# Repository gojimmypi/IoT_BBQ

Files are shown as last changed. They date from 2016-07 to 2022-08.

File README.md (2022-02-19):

# IoT BBQ

Project for [Making Embedded Systems](https://lms.classpert.com/classpertx/courses/making-embedded-systems/cohort) class.

See [Assignments](./Assignments/README.md)

The Imaginary Embedded System that does not exist for the _Making Embedded Systems_ class is the Barbeque Grill 
monitoring system project started (and abandoned) 5 years ago as noted below that was intially tinkered with using
an ESP8266 an the `LUA` language, but never completed. 

The `IoT_BBQ` system is a monitoring device to primarily measure the weight of the propane tank to ensure that
when it is time to cook, that the fuel supply is not nearly empty. Having an electronic scale monitoring the weight
is much more precise, accurate, and convenient as compared to the mechanical spring scales. A custom solution is also 
needed as the amount of available physical space is so limited, that even a bathroom scale is not practical for both 
size and viewing angle.

A premium version of this system will also include internal grill box temperature, as well as various atmospheric sensors, 
such as ambient temperature and pressure. 

Some sort of information display will be needed: either a local LCD panel and/or a web interface.

Components needed include:

- Controller board
- Power Supply
- Load cell (weight sensor) such as the [SparkFun HX711](https://www.sparkfun.com/products/13879) with this sample [Arduino Library](https://github.com/bogde/HX711). See also [non-arduino](https://github.com/nimaltd/HX711)
, and [ST forum](https://community.st.com/s/question/0D50X0000AusvItSQI/trying-to-interface-with-an-hx711-load-cell-amp)
- Temperature sensor
- Other atmospheric sensors
- Enclosure
- Mounting hardware

Yes, the [ST USB Driver](https://www.st.com/en/development-tools/stsw-link009.html) needs to be installed manually.

## Diagram:



## Weight Sensor

The HX711 weight sensor is powered with +3.3V and conencted to Arduino Header Pins `D8` (`ARD.D8` == `GPIO_PIN_8` == `PB2`) and `D9` (`GPIO_PIN_9`) located at `CN1` pins 1 and 2, 
as shown on page 50 of the [B-L475E-IOT01A (UM2153) User manual](https://www.st.com/resource/en/user_manual/um2153-discovery-kit-for-iot-node-multichannel-communication-with-stm32l4-stmicroelectronics.pdf)

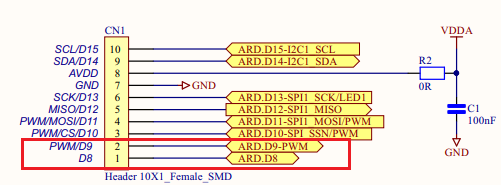
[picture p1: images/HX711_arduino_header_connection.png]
HX711_arduino_header_connection


## Display

The SSD1306 display is connected to I2C `SCL/D15` (`GPIO_PIN_15`) and `SDA/D14` (`GPIO_PIN_14`) located at `CN1` pins 9 and 10, 
as shown on page 50 of the [B-L475E-IOT01A (UM2153) User manual](https://www.st.com/resource/en/user_manual/um2153-discovery-kit-for-iot-node-multichannel-communication-with-stm32l4-stmicroelectronics.pdf)

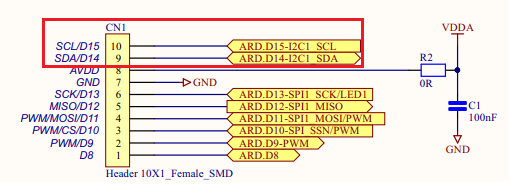
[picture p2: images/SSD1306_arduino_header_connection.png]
SSD1306_arduino_header_connection


## B-L475E-IOT01A Connections

HX711
- PD_SCK = GPIO_PIN_2; //  ARD.D8 = PB2  0x0004
- DOUT = GPIO_PIN_15;  //  ARD.D9 = PA15 0x8000

GPIO_init; old HX711
- GPIOB GPIO_PIN_8
- GPIOB GPIO_PIN_9

HAL_TIM_MspPostInit
- GPIOA / GPIO_PIN_0

LED
- GPIOA GPIO_PIN_5;
- GPIOB GPIO_PIN_14;

SSD1306
- DC GPIOB GPIO_PIN_14
- Reset GPIOA GPIO_PIN_8
- 

Button
- GPIOC, GPIO_PIN_13  (interrupt)

pwm_MX_GPIO_Init
- GPIOA GPIO_PIN_8

ConfigureI2CPins
- GPIOC GPIO_PIN_0 
- GPIOC GPIO_PIN_1

Pressure, Humidity, Temperature Sensors I2C. See [line 364 of stm32l475e_iot01.c](https://github.com/STMicroelectronics/STM32CubeL4/blob/5e1553e07706491bd11f4edd304e093b6e4b83a4/Drivers/BSP/B-L475E-IOT01/stm32l475e_iot01.c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):

- SCL = GPIOB GPIO_PIN_10
- SDA = GPIOB GPIO_PIN_11

### CN1

See Table 4 ARDUINO® connector pinout on page 31 of the [B-L475E-IOT01A (UM2153) User manual](https://www.st.com/resource/en/user_manual/um2153-discovery-kit-for-iot-node-multichannel-communication-with-stm32l4-stmicroelectronics.pdf):

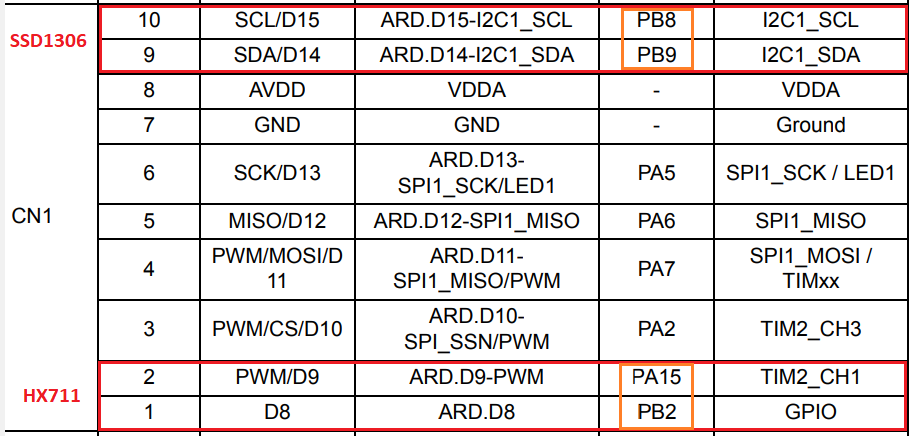
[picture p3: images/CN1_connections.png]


## Additional Resources

See also:

### Mechanical

- Statasys Grabcad Community [Propane Tank](https://grabcad.com/library/propane-tank)

## Electronics

- [STM32 Discovery Kits](https://www.st.com/en/evaluation-tools/stm32-discovery-kits.html#products)
- [ST-LINK, ST-LINK/V2, ST-LINK/V2-1, STLINK-V3 USB driver signed for Windows7, Windows8, Windows10](https://www.st.com/content/my_st_com/en/products/development-tools/software-development-tools/stm32-software-development-tools/stm32-utilities/stsw-link009.license=1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)
- [ARM MBED DISCO-L475VG-IOT01A (B-L475E-IOT01A](https://os.mbed.com/platforms/ST-Discovery-L475E-IOT01A/) (this is where the link on the OTG file points)
- [Mouser B-L475E-IOT01A Data Brief ](https://www.mouser.com/datasheet/2/389/b-l475e-iot01a-1848022.pdf)
- [Mouser Discovery Kit for IoT Node](https://www.mouser.com/pdfdocs/RS7706_IC_STM32L475E-IOT01A1_0517d.pdf) (this is the front and back of the insert card in for the shipped product)
- [Mouser STMicroelectronics B-L475E-IOT01A Discovery Kit for IoT Node](https://www.mouser.com/new/stmicroelectronics/stm-b-l475e-iot01a-kit/)

### Development

- [STM32Cube MCU Package for STM32L4 series and STM32L4 Plus series (HAL, Low-Layer APIs and CMSIS, USB, TouchSensing, File system, RTOS)](https://www.st.com/en/embedded-software/stm32cubel4.html#tools-software)
- [VisualGDB Developing STM32 projects with Visual Studio tutorial](https://visualgdb.com/tutorials/arm/stm32/)
- [STM32L4 Discovery kit IoT node software](https://www.st.com/en/evaluation-tools/b-l475e-iot01a.html#tools-software)
- [STM32L4 series of ultra-low-power MCUs](https://www.st.com/en/microcontrollers-microprocessors/stm32l4-series.html)
- [The FreeRTOS™ Reference Manual](https://www.freertos.org/fr-content-src/uploads/2018/07/FreeRTOS_Reference_Manual_V10.0.0.pdf)

### Example Code

- [bogde/HX711](https://github.com/bogde/HX711)
- [nimaltd/HX711](https://github.com/nimaltd/HX711/blob/master/hx711.c)
- [ODriveRobotics Samnple Code](https://github.com/odriverobotics/ODrive/blob/master/Firmware/Drivers/STM32/stm32_system.h)
- [RTOS Thread Management](https://www.keil.com/pack/doc/CMSIS/RTOS/html/group__CMSIS__RTOS__ThreadMgmt.html)

### Coding Reference

- Microchip [AVR035: Efficient C Coding for AVR](https://ww1.microchip.com/downloads/en/Appnotes/doc1497.pdf)
- [Idioms for using C++ in C programs (Part 1 of 2)](http://www.olivierlanglois.net/idioms_for_using_cpp_in_c_programs.html)

- [VS Code Extension: Markdown PDF](https://marketplace.visualstudio.com/items?itemName=yzane.markdown-pdf)

My original README follows:

# IoT_BBQ
ESP8266 Based Grill Temperature and Propane Tank Weight Project

First you need a NodeMCU ESP8266 like this one:

http://www.ebay.com/itm/400999083640

Note it has a CH340G USB chip, so works well with Windows 10

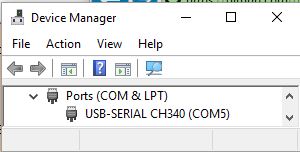
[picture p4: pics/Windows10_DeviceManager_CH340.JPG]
Windows Device Manager


Next, download flasher from https://github.com/nodemcu/nodemcu-flasher

In the \Resources\Binaries directory, there are Lua firmware images (one support floats, the other only ints)

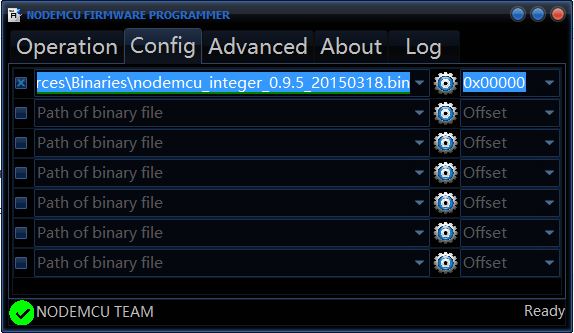
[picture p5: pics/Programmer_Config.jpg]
config setting


Once you've uploaded the image, this tool can be helpful for getting Lua code onto your device:

http://benlo.com/esp8266/ 

You can read more about NodeLUA here: https://nodelua.org/

Next, you will need a MAX6675 Module + K Type Thermocouple Temperature Sensor like this one: 

http://www.ebay.com/itm/400798924042

see this respository for spec sheet on MAX6675, or visit 

https://datasheets.maximintegrated.com/

Note that for connection to the ESP8266, you'll need to pull CS down to ground with a 10k resistor so the ESP8266 will boot.

I soldered a resistor on the board between those pins.

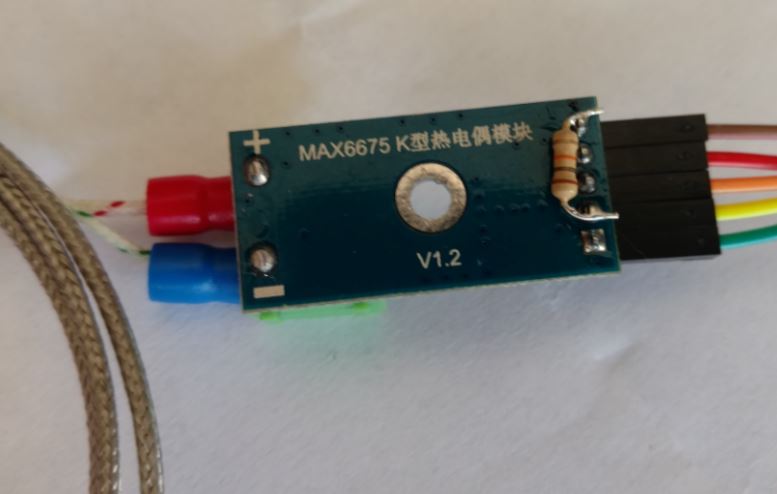
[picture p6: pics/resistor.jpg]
soldered resistor


Connect your thermocouple to the ESP8266 (see pics for pinout)

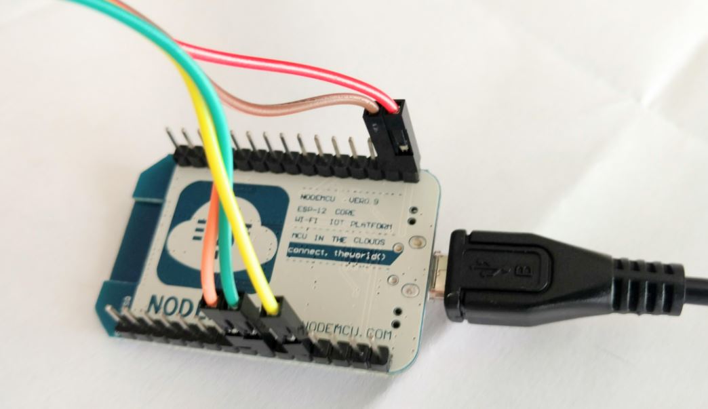
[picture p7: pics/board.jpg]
board wiring


Once everything is connected, setup ESP8266 to connect to WiFi. 

```Lua
wifi.setmode(wifi.STATION)
wifi.sta.config("yourWiFiName","yourWifFiPassword")
wifi.sta.connect()
```

Consider security issues of hard coding password. You can configure once & ESP8266 will remember after reboot.

Next, find your device on the local network segment. For this, I use fing:

https://play.google.com/store/apps/details?id=com.overlook.android.fing&hl=en

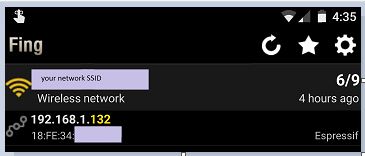
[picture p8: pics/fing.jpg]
fing


Once you find the device, click on it, and scan for open ports. You should have port 80 open:

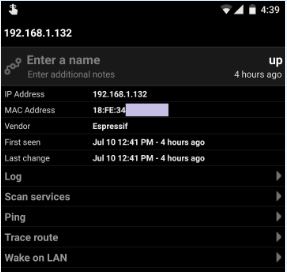
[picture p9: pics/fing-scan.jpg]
fing scan


If you found the ESP8266 on your network, upload the thermocouple.lua file:

thermocouple.lua upload

If everything is working, you'll see the temperature on your phone! (temperature shown in Celsius)

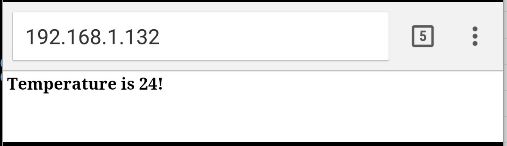
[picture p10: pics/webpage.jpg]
webpage sample


Load the file in init.lua to maintain web server operations after a reboot. I found that it is best to delete the init.lua file, reboot, then load a fresh init.lua when making changes. Again, fing is handy for detecting port 80 being open or not.

Next weekend, I will work on adding the weight sensor. I used one like this:

20KG Scale Load Cell Weight Weighing Sensor +HX711 Weighing Sensors AD Module 

http://www.ebay.com/itm/281916193412

feedback, comments, suggestions? contact me at gmail or twitter.

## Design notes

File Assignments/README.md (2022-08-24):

# Assignments for [Making Embedded Systems](https://lms.classpert.com/classpertx/courses/making-embedded-systems/cohort) class.

- [Exercise 1](./Exercise_1.md)
- [Exercise 2.1](./Exercise_2_1.md)
- [Exercise 2.2](./Exercise_2_2.md)
- [Exercise 3a](./Exercise_3a.md)
- [Exercise 3b](./Exercise_3b.md)  See also [Class Materials](https://drive.google.com/drive/folders/1xk9AmmLDqESqimDk_KvxHu6KfzpaYX9M), [spi_flash.h](https://drive.google.com/file/d/12dw-pZiKiK1vi4gv49W1x6np5uzCH_cV/view)
- [Exercise 4](./Exercise_4.md) 
- [Exercise 5](./Exercise_5.md) 
- [Exercise 6](./Exercise_6.md) 
- [Exercise 7](./Exercise_7.md) 
- [Exercise 8](./Exercise_8.md) 
- [Exercise 9](./Exercise_9.md)
- [Final Project](./Final_Project.md) and [Final Project Report](./Final_Project_Report.md)

[Final Project Video](https://youtu.be/YIoqKTbCUQQ)

# Final Project Submission

See [Final Project Submission](./Final_Project_Submission.md)

# Links

Hardware
- [STM32L4 Series](https://www.st.com/en/microcontrollers-microprocessors/stm32l4-series.html)
- [Mouser B-L475E-IOT01A1](https://www.mouser.com/ProductDetail/stmicroelectronics/b-l475e-iot01a1/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)
- [Mouser SPBTLE-RF](https://www.mouser.com/ProductDetail/STMicroelectronics/SPBTLE-RF?qs=k5OWtXsTJaq8f%252B3JiZyqyw%3D%3D), [Datasheet](https://www.mouser.com/datasheet/2/389/SGST_S_A0003533199_1-2576929.pdf)
- [ST B-L475E-IOT01A STM32L4 Discovery kit IoT node](https://www.st.com/en/evaluation-tools/b-l475e-iot01a.html#)
- [Migrating from STM32L4 and STM32L4+ to STM32L5 Series microcontrollers (AN5138)](https://www.st.com/resource/en/application_note/dm00476869-migrating-from-stm32l4-and-stm32l4-to-stm32l5-series-microcontrollers-stmicroelectronics.pdf)

Specifications

- [User Manual (57 pages) STM32L4 Discovery kit for the IoT node (B-L475E-IOT01A)](https://www.st.com/resource/en/user_manual/um2153-discovery-kit-for-iot-node-multichannel-communication-with-stm32l4-stmicroelectronics.pdf)
- [Data brief (4 pages) ST B-L475E-IOT01A](https://www.st.com/resource/en/data_brief/b-l475e-iot01a.pdf) Discovery kit for IoT node, multi-channel communication with STM32L4
- [STM32L475VG](https://www.st.com/en/microcontrollers-microprocessors/stm32l475vg.html#), [STM32L475xx datasheet (204 pages)](https://www.st.com/resource/en/datasheet/stm32l475vg.pdf)
- [STM32L475xx Datasheet AN4666](https://www.st.com/resource/en/datasheet/stm32l475vg.pdf)

Application Notes

- [Using the STM32F2, STM32F4 and STM32F7 Series DMA controller AN4031](https://www.st.com/content/ccc/resource/technical/document/application_note/27/46/7c/ea/2d/91/40/a9/DM00046011.pdf/files/DM00046011.pdf/jcr:content/translations/en.D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)
- [Using the STM32F0/F1/F3/Gx/Lx Series DMA controller AN2548](https://www.st.com/resource/en/application_note/an2548-using-the-stm32f0f1f3gxlx-series-dma-controller-stmicroelectronics.pdf)
- [Parallel synchronous transmission using GPIO and DMA](https://www.st.com/resource/en/application_note/an4666-parallel-synchronous-transmission-using-gpio-and-dma-stmicroelectronics.pdf)

Examples

- [B-L475E-IOT01A/Examples](https://github.com/STMicroelectronics/STM32CubeL4/tree/master/Projects/B-L475E-IOT01A/Examples) (not many examples)
- [STM32CubeL4/Projects/B-L475E-IOT01A/Examples/BSP/Src/](https://github.com/STMicroelectronics/STM32CubeL4/tree/master/Projects/B-L475E-IOT01A/Examples/BSP/Src)
- Digi-Key [Getting Started with STM32 - Timers and Timer Interrupts](https://www.digikey.com/en/maker/projects/getting-started-with-stm32-timers-and-timer-interrupts/d08e6493cefa486fb1e79c43c0b08cc6)

Peripherals

- [Inventek Systems ISM43362-M3G-L44-E/U Serial-to-WiFi Module](https://www.inventeksys.com/ism4336-m3g-l44-e-embedded-serial-to-wifi-module/), [ISM43362-M3G-L44 Datasheet](http://www.inventeksys.com/wp-content/uploads/ISM43362_M3G_L44_Functional_Spec.pdf)

GPIO
- [STM32 Understanding GPIO Settings](https://electronics.stackexchange.com/questions/156930/stm32-understanding-gpio-settings)

- [FreeRTOS: osDelay vs HAL_delay](https://stackoverflow.com/questions/42276313/freertos-osdelay-vs-hal-delay)

mbed

- [os.mbed.com DISCO-L475VG-IOT01A (B-L475E-IOT01A)](https://os.mbed.com/platforms/ST-Discovery-L475E-IOT01A/)
- [sensors](https://ide.mbed.com/compiler/#nav:/DISCO_L475VG_IOT01-Sensors-BSP/main.cpp;)

Visual GDB

- [Creating Advanced STM32CubeMX-based Projects with VisualGDB](https://visualgdb.com/tutorials/arm/stm32/cube/advanced/)
- [Controlling STM32 Hardware Timers using HAL](https://visualgdb.com/tutorials/arm/stm32/timers/hal/)
- [Using STM32 timers in PWM mode](https://visualgdb.com/tutorials/arm/stm32/pwm/)
- sysprogs github [visualgdb/ARM tutorials](https://github.com/sysprogs/tutorials/tree/master/visualgdb/ARM)
- [sysprogs/BSPTools](https://github.com/sysprogs/BSPTools)

RTOS

- [CMSIS-RTOS2 Documentation](https://arm-software.github.io/CMSIS_5/RTOS2/html/index.html)
- GitHub [CMSIS Version 5](https://github.com/ARM-software/CMSIS_5)
- [The FreeRTOS Reference Manual](https://www.freertos.org/fr-content-src/uploads/2018/07/FreeRTOS_Reference_Manual_V10.0.0.pdf)
- [stackoverflow: What are valid values of `HAL_NVIC_SetPriority()` when using STM32 and FreeRTOS?](https://stackoverflow.com/questions/50243996/what-are-valid-values-of-hal-nvic-setpriority-when-using-stm32-and-freertos)
- FreeRTOS [Memory Management](https://www.freertos.org/a00111.html)
- STM32CubeL4 FreeRTOS [xPortGetFreeHeapSize](https://github.com/STMicroelectronics/STM32CubeL4/blob/master/Middlewares/Third_Party/FreeRTOS/Source/portable/MemMang/heap_4.c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)

Debuggers

- [ST-LINK/V2 in-circuit debugger/programmer for STM8 and STM32](https://www.st.com/en/development-tools/st-link-v2.html)
- [Segger J-Link / J-Trace User Guide](https://www.segger.com/downloads/jlink/UM08001)
- [Converting ST-LINK On-Board Into a J-Link](https://www.segger.com/products/debug-probes/j-link/models/other-j-links/st-link-on-board/)

Sample Code

- [ST community: delay in a microsecond(us)](https://community.st.com/s/question/0D50X0000BGkxmCSQR/stm32l462-delay-in-a-microsecondus)
- [a-podshivalov/RIOT](https://github.com/a-podshivalov/RIOT) sample code
- [bogde/HX711](https://github.com/bogde/HX711/blob/master/src/HX711.cpp)
- [ArduinoCore-samd/cores/arduino/wiring_private.h](https://github.com/arduino/ArduinoCore-samd/blob/master/cores/arduino/wiring_private.h)
- [ArduinoCore-avr/cores/arduino/wiring_shift.c](https://github.com/arduino/ArduinoCore-avr/blob/9f8d27f09f3bbd1da1374b5549a82bda55d45d44/cores/arduino/wiring_shift.c) - original code for [shiftIn()](https://www.arduino.cc/reference/en/language/functions/advanced-io/shiftin/)
- [logicalelegance/midifun/Core/Console/console.c](https://github.com/logicalelegance/midifun/blob/master/Core/Console/console.c)
- [stackoverflow: STM32 HAL timer interrupt isn't triggered](https://stackoverflow.com/questions/40323461/stm32-hal-timer-interrupt-isnt-triggered)
- [stackoverflow: STM32F3 Discovery - Implement GPIO-Interrupt](https://stackoverflow.com/questions/40057581/stm32f3-discovery-implement-gpio-interrupt)
- [STM32-libraries/Drivers/LCD/Adafruit_GFX.h](https://github.com/mindThomas/STM32-libraries/blob/master/Drivers/LCD/Adafruit_GFX.h)

IoT Management Tools

- [What Is IoT Device Management and Why Do You Need It?](https://www.digi.com/blog/post/what-is-iot-device-management)
- [Memfault - Cloud Debugging and Observability for Your IoT Devices](https://memfault.com/); [Monitoring Fleet Health with Heartbeat Metrics](https://interrupt.memfault.com/blog/device-heartbeat-metrics); [Defensive Programming](https://interrupt.memfault.com/blog/defensive-and-offensive-programming)
- [Tyler Hoffman on embedded.fm to discuss the issues associated with embedded devices at consumer scale](https://embedded.fm/episodes/390).
- [Monitor your entire Azure IoT environment with Datadog](https://www.datadoghq.com/dg/monitor/azure-iot/)
- [ThingsBoard Open-source IoT Platform](https://thingsboard.io/)
- [Azure IoT](https://azure.microsoft.com/en-us/overview/iot/#overview)
- [AWS IoT Device Management](https://aws.amazon.com/iot-device-management/)

Hard Faulkts

- [How to debug a HardFault on an ARM Cortex-M MCU](https://interrupt.memfault.com/blog/cortex-m-fault-debug#fn:8)
- [Slides from live class](https://drive.google.com/file/d/11M6Tn6bw0GAD549te2_HMGIEa5ajErI1/view?usp=sharing)

Other Stuff

- wikipedia [.bss block starting symbol](https://en.wikipedia.org/wiki/.bss)
- [pinout](https://pinout.readthedocs.io/en/latest/)
- [cmocka unit testing framework for C with support for mock objects](https://cmocka.org/)
- [asciiflow.com](https://asciiflow.com/#/)
- [app.diagrams.net](https://app.diagrams.net/)
- [lucidChart Block diagram maker](https://www.lucidchart.com/pages/examples/block-diagram-maker)
- [drawio-desktop](https://github.com/jgraph/drawio-desktop/releases/tag/v15.8.7)
- [Everything You Never Wanted To Know About Linker Script](https://mcyoung.xyz/2021/06/01/linker-script/)
- [Basic Concepts in Interrupts](https://web.sonoma.edu/users/f/farahman/sonoma/courses/es310/310_arm/lectures/Chapter_11_Interrupts_ARM.pdf) from [EE 310/310L: Microprocessors and System Design - Introducing ARM](https://web.sonoma.edu/users/f/farahman/sonoma/courses/es310/310_arm/)
- [STM32Cube initialization code generator](https://www.st.com/en/development-tools/stm32cubemx.html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),  specifically [STM32 configuration and initialization C code generation](https://www.st.com/resource/en/data_brief/stm32cubemx.pdf)
- [hackaday stm32cubemx makes makefiles](https://hackaday.com/2017/07/15/stm32cubemx-makes-makefiles/)
- [godbolt.org](https://godbolt.org/)

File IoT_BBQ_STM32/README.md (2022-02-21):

# IoT BBQ STM32

## Build from Visual Studio

The [IoT_BBQ_STM32](https://github.com/gojimmypi/IoT_BBQ/blob/main/IoT_BBQ_STM32/IoT_BBQ_STM32.sln) is a Visual Studio 2019 solution file with a SysProgs VisualGDB extension project.

Build simply by right-click and build...

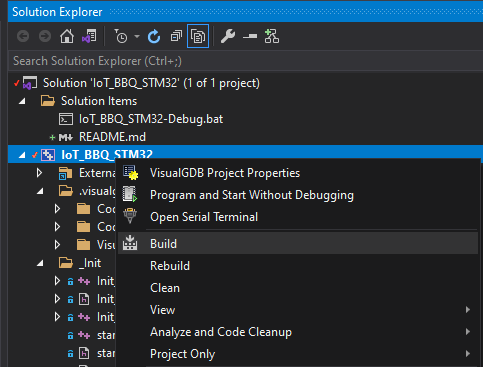
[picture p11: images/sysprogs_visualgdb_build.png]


## Build from a batch file:

Assumes toolchain is installed in: `c:\SysGCC\arm-eabi\bin\arm-none-eabi-gcc.exe`

```
SET WORKSPACE=C:\workspace\
c:
if not exist "%WORKSPACE%" mkdir "%WORKSPACE%"

cd "%WORKSPACE%"
if exist "%WORKSPACE%" goto error

git clone https://github.com/gojimmypi/IoT_BBQ.git
cd "%WORKSPACE%"
cd IoT_BBQ\IoT_BBQ_STM32

goto done
:error
echo Error 

:done
echo done!

```

For more information, see [Final Project](../Assignments/Final_Project.md).

Testing the new [Include diagrams in your Markdown files with Mermaid](https://github.blog/2022-02-14-include-diagrams-markdown-files-mermaid/) feature:

# Main

```mermaid
graph TD
    A[Startup] -->|Init| B(Start Threads)
    B --> LED1[LED1 Blinky]
    B --> LED2[LED2 Blinky]
    B --> UART
    B --> DISPLAY
    B --> PWM[PWM]
    LED1 --> ShowWeight[Display Weight]
    ShowWeight --> ShowPressure[Display Pressure]
    ShowPressure --> Blinky1State{LED_GetMode}
    Blinky1State --> |IsBlinking| LED1_blink[LED1 Blink]
    Blinky1State --> |AlwaysOn| LED1_On[LED1 On]
    Blinky1State --> |AlwaysOff| LED1_Off[LED1 Off]
    Blinky1State --> |default| LED1_default[Set Mode IsBlinking]
    LED1_blink --> ShowWeight
    LED1_On --> ShowWeight
    LED1_Off --> ShowWeight
    LED1_default --> ShowWeight
    PWM -->|One| D[experiments]
```

# Overall System

```mermaid
graph TD
    A[Startup] -->|Init| B(Start Threads)
    B --> LED1[LED1 Blinky]
    B --> LED2[LED2 Blinky]
    B --> UART
    B --> DISPLAY_Thread1[Display]
    B --> PWM[PWM]

    LED1 --> ShowWeight[Display Weight]
    ShowWeight --> ShowPressure[Display Pressure]
    ShowPressure --> Blinky1State{LED_GetMode}
    Blinky1State --> |IsBlinking| LED1_blink[LED1 Blink]
    Blinky1State --> |AlwaysOn| LED1_On[LED1 On]
    Blinky1State --> |AlwaysOff| LED1_Off[LED1 Off]
    Blinky1State --> |default| LED1_default[Set Mode IsBlinking]
    LED1_blink --> ShowWeight
    LED1_On --> ShowWeight
    LED1_Off --> ShowWeight
    LED1_default --> ShowWeight

    LED2 --> Blinky2State{LED_GetMode}
    Blinky2State --> |IsBlinking| LED2_blink[blink_Count = 1]
    Blinky2State --> |AlwaysOn| LED2_On[blink_Count = 2]
    Blinky2State --> |AlwaysOff| LED2_Off[blink_Count = 3]
    Blinky2State --> |default| LED2_default[blink_Count = 4]
    LED2_blink --> LED2
    LED2_On --> LED2
    LED2_Off --> LED2
    LED2_default --> LED2

    DISPLAY_Thread1 --> InitDisplay
    InitDisplay --> CheckForLongPress{Long Press?}
    CheckForLongPress --> |yes|Tare
    CheckForLongPress --> |no|ShowWeightDisplay
    Tare --> ShowWeightDisplay
    ShowWeightDisplay --> CheckForLongPress

    PWM -->|One| D[experiments]

```  

# Threads

```mermaid
graph TD
    A[Startup] -->|Init| B(Start Threads)
    B --> LED1[LED1 Blinky]
    B --> LED2[LED2 Blinky]
    B --> UART
    B --> DISPLAY_Thread1[Display]
    B --> PWM[PWM]
```

# LED1

```mermaid
graph TD
    LED1 --> ShowWeight[Display Weight]
    ShowWeight --> ShowPressure[Display Pressure]
    ShowPressure --> Blinky1State{LED_GetMode}
    Blinky1State --> |IsBlinking| LED1_blink[LED1 Blink]
    Blinky1State --> |AlwaysOn| LED1_On[LED1 On]
    Blinky1State --> |AlwaysOff| LED1_Off[LED1 Off]
    Blinky1State --> |default| LED1_default[Set Mode IsBlinking]
    LED1_blink --> ShowWeight
    LED1_On --> ShowWeight
    LED1_Off --> ShowWeight
    LED1_default --> ShowWeight
```

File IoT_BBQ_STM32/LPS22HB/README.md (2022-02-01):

LPS22HB MEMS nano pressure sensor: 260-1260 hPa absolute digital output barometer

See https://www.st.com/resource/en/datasheet/lps22hb.pdf

Sample code: https://github.com/STMicroelectronics/STM32CubeL4/tree/master/Drivers/BSP/B-L475E-IOT01

See also:    https://github.com/STMicroelectronics/STM32CubeL4/blob/master/Drivers/BSP/B-L475E-IOT01/stm32l475e_iot01.c

Uumidity:    https://github.com/STMicroelectronics/STM32CubeL4/blob/master/Drivers/BSP/B-L475E-IOT01/stm32l475e_iot01_hsensor.h

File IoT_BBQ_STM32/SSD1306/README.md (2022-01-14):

# stm32-ssd1306

STM32 library for working with OLEDs based on SSD1306, supports I2C and 4-wire SPI.
It also works with SH1106, SH1107 and SSD1309 which are compatible with SSD1306.

Please see `ssd1306/ssd1306_conf_template.h` and `examples` directory for more details.

See also:

* https://github.com/afiskon/stm32-i2c-lcd-1602
* https://github.com/afiskon/stm32-ssd1351
* https://github.com/afiskon/stm32-st7735
* https://github.com/afiskon/stm32-ili9341

The code is based on
[4ilo/ssd1306-stm32HAL](https://github.com/4ilo/ssd1306-stm32HAL) library
developed by Olivier Van den Eede ( [@4ilo](https://github.com/4ilo) ) in 2016.

There is a [DuyTrandeLion/nrf52-ssd1309](https://github.com/DuyTrandeLion/nrf52-ssd1309) port to nRF52 of this library made by [@DuyTrandeLion](https://github.com/DuyTrandeLion) in 2020.

See also: [Sysprogs VisualGDB Using the I2C Interface on the STM32 Devices](https://visualgdb.com/tutorials/arm/stm32/i2c/)

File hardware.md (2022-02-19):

Hardware used for [Making Embedded Systems](https://lms.classpert.com/classpertx/courses/making-embedded-systems/cohort) class.

Dev Board: [B-L475E-IOT01A1](https://www.st.com/en/evaluation-tools/b-l475e-iot01a.html)

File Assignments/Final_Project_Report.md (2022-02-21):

# Final Project Report

This Final Project Report is a supplement to the [Final Project Minimum Project Requirement Detail](./Final_Project.md).
An embedded microscontroller was used to create a propane tank weight measurement system. 
[Source code](https://github.com/gojimmypi/IoT_BBQ/tree/main/IoT_BBQ_STM32) is available on GitHub.

See also the [YouTube Video](https://youtu.be/YIoqKTbCUQQ):

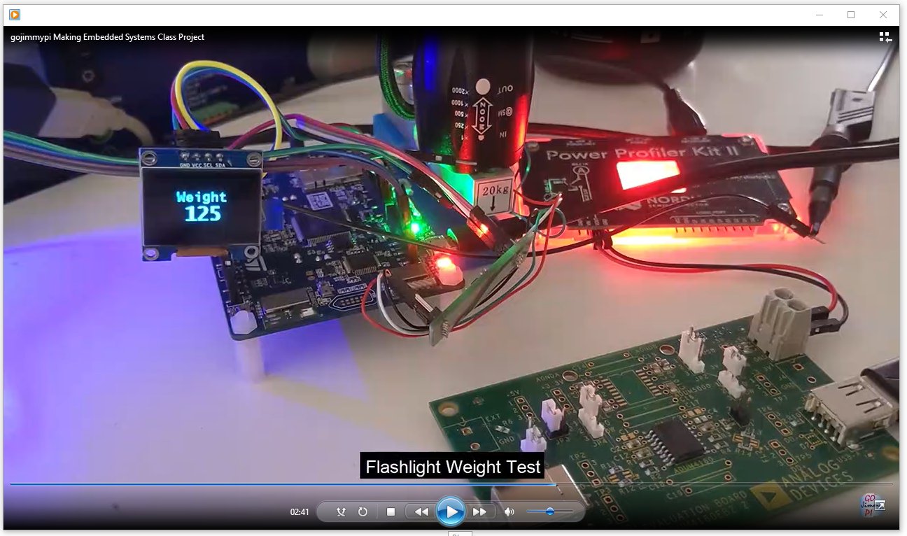
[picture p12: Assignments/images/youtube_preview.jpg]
(https://youtu.be/YIoqKTbCUQQ)

<br/><br/>

## Application Description

This application is an embedded controller to monitor grill propane tank weight to replace the existing mechanical spring scale:

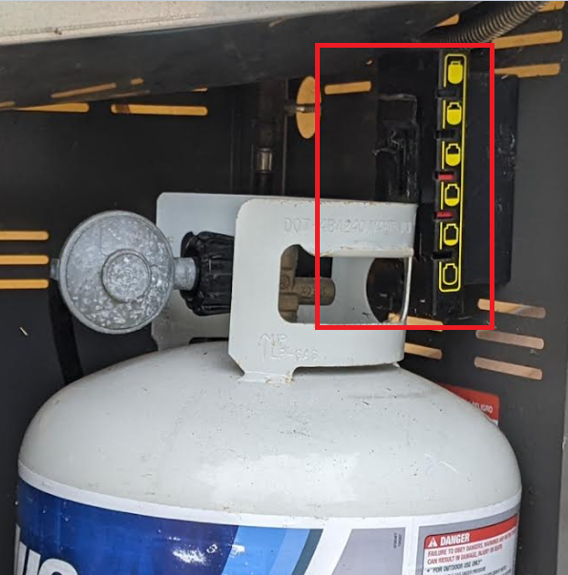
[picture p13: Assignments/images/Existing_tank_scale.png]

<br/><br/>

## Hardware Description

This project uses the [STM32L475VG](https://www.st.com/resource/en/datasheet/stm32l475vg.pdf), 
part of the [STM32 Ultra Low Power](https://www.st.com/en/microcontrollers-microprocessors/stm32-ultra-low-power-mcus.html) Arm Cortex-M4 32-bit MCU+FPU series
found on the  [B-L475E-IOT01A Discovery Board](https://www.st.com/resource/en/user_manual/um2153-discovery-kit-for-iot-node-multichannel-communication-with-stm32l4-stmicroelectronics.pdf).
<br/><br/>

## Software description

The application is written in C/C++ and targets the STM32 ARM Platform. 
<br/><br/>

### Describe the code in general

The code is a multi-threaded FreeRTOS embedded application. There are 5 threads named LED1, LED2, UART1, DISPLAY, and PWM.

#### LED1 Thread

The [LED1 Thread](https://github.com/gojimmypi/IoT_BBQ/blob/main/IoT_BBQ_STM32/_main_LED_Thread1.c) is a simple state machine and controls LED1 (blinky, on, or off).
This thread also sends pressure reading and scale weight text to the UART.
<br/><br/>

#### LED2 Thread

The [LED1 Thread](https://github.com/gojimmypi/IoT_BBQ/blob/main/IoT_BBQ_STM32/_main_LED_Thread2.c) monitors the state machine and blinks LED2 depending on the current state:

* `IsBlinking` - one blink
* `AlwaysOn` - two blinks
* `AlwaysOff` - three blinks
<br/><br/>

#### UART1 Thread

Just to test RTOS concurrency (and hard fault avoidance!) the [UART1 Thread]() sends a "Hello UART1" message
to the UART about every 1.35 seconds. An odd number was chosen to ensure pseudo-random conflicts in timing
with other messages.

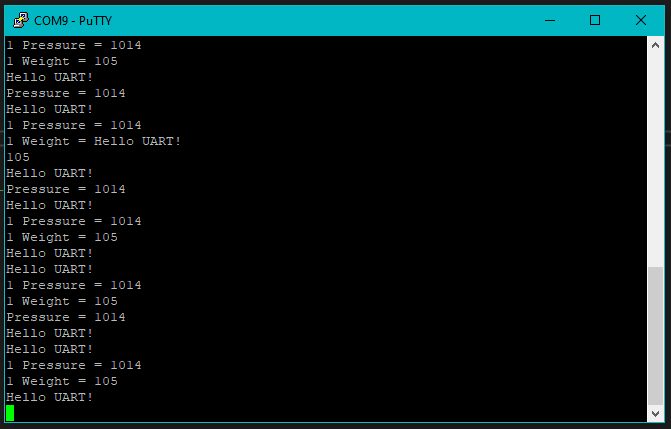
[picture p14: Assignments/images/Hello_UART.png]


This particular screen snip (above) is interesting. Note the seemingly stray "105" value. Apparently this is where the thread tried to grab a mutex to use the UART, but one was not available
on a timely basis, so it skipped the entire "1 weight" part of the message. Recall this occurs in [two steps](https://github.com/gojimmypi/IoT_BBQ/blob/29255d7aa78ec70aa6fd3b76e06db336202eda09/IoT_BBQ_STM32/_main_LED_Thread1.c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):

```
        UART_TxMessageIntValue(WeightMessage, sizeof(WeightMessage), CurrentTankWeight);
        // (RTOS Thread swtich occured around here)
        UART_TxMessage(CrLf, sizeof(CrLf));
```
<br/><br/>

#### DISPLAY Thread

The [Display Thread](https://github.com/gojimmypi/IoT_BBQ/blob/main/IoT_BBQ_STM32/DISPLAY/DISPLAY.cpp) is where the scale is monitored and the value displayed on the screen.
There's also a small state machine monitoring for a button long press to then tare the scale and save the offset value to flash.
<br/><br/>

#### PWM Thread

The [PWM thread](https://github.com/gojimmypi/IoT_BBQ/blob/main/IoT_BBQ_STM32/_main_pwm_thread.c) is included only for "interesting" experiements and is not required for basic functionality.

After some initial code experiments, the thread runs in a loop sending barometric pressure reading to the UART every 2 seconds.

Code Explorer View of [main()](https://github.com/gojimmypi/IoT_BBQ/blob/main/IoT_BBQ_STM32/_main.c)

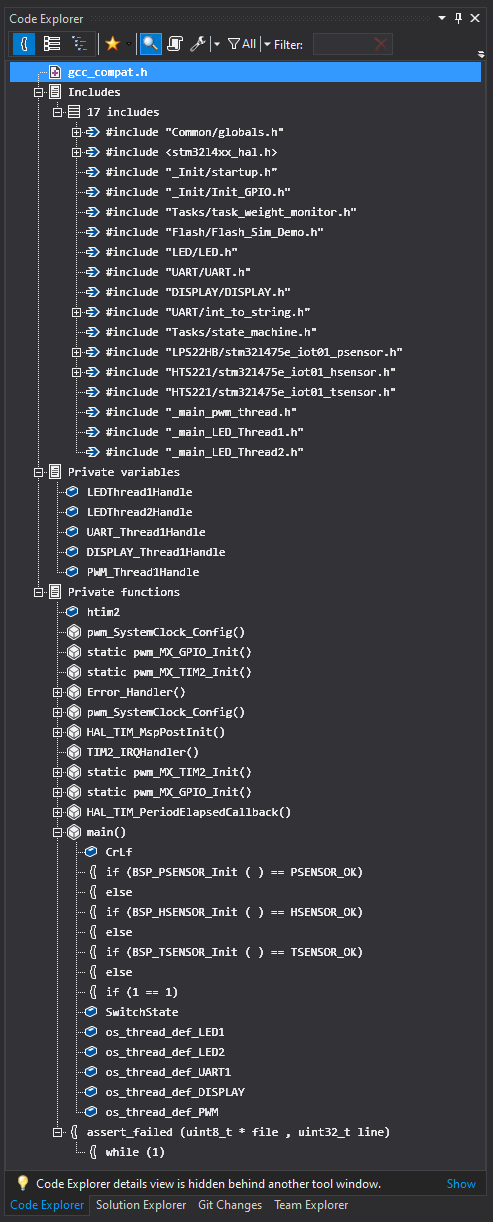
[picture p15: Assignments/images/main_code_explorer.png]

<br/><br/>

### Describe the parts you wrote in some detail (maybe 3-5 sentences per module)

The main code repository can be found at [github.com/gojimmypi/IoT_BBQ/tree/main/IoT_BBQ_STM32](https://github.com/gojimmypi/IoT_BBQ/tree/main/IoT_BBQ_STM32). MIT License.

* [Display Code](https://github.com/gojimmypi/IoT_BBQ/tree/main/IoT_BBQ_STM32/DISPLAY) was written specifically for this project. MIT License.

* [Flash Config](https://github.com/gojimmypi/IoT_BBQ/blob/main/IoT_BBQ_STM32/Flash/flash_config.h) was created from scratch for this project. MIT license.

* [LED Blinky and State Machine](https://github.com/gojimmypi/IoT_BBQ/tree/main/IoT_BBQ_STM32/LED) created by gojimmypi for this project. MIT license.

* [UART](https://github.com/gojimmypi/IoT_BBQ/tree/main/IoT_BBQ_STM32/UART) created for this project, MIT license. Uses [stm32l4xx_hal.h](https://github.com/STMicroelectronics/STM32CubeL4/blob/master/Drivers/STM32L4xx_HAL_Driver/Inc/stm32l4xx_hal.h) 
assumed to still be [BSD 3-Clause license](https://github.com/STMicroelectronics/STM32CubeL4/blob/d023c0d560ace11509f9b761c8913a9e48fcf194/Drivers/STM32L4xx_HAL_Driver/Src/stm32l4xx_hal.c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)
<br/><br/>

### Describe code you re-used from other sources, including the licenses for those

This project was created using the [Sysprogs VisualGDB Extension](https://visualgdb.com/?features=embedded) for [Visual Studio 2019](https://docs.microsoft.com/en-us/visualstudio/releases/2019/release-notes).
A tiny amount of initialization code was generated using the [STM32CubeIDE](https://www.st.com/en/development-tools/stm32cubeide.html). 

* [HX711 Arduino Library](https://github.com/bogde/HX711) was ported to this STM32 HAL environment with FreeRTOS support. MIT License.

* [STM hsensor HAL](https://github.com/STMicroelectronics/STM32CubeL4/blob/master/Drivers/BSP/B-L475E-IOT01/stm32l475e_iot01_hsensor.c) BSD 3-Clause license. 

* [STM Pressure Sensor HAL](https://github.com/STMicroelectronics/STM32CubeL4/blob/master/Drivers/BSP/B-L475E-IOT01/stm32l475e_iot01_psensor.h) BSD 3-Clause license

* [ssd1306 display driver](https://github.com/afiskon/stm32-ssd1306) was created by Aleksander Alekseev and [modified](https://github.com/gojimmypi/IoT_BBQ/commits/main/IoT_BBQ_STM32/SSD1306) for this project.  MIT License

* [Flash HAL](https://github.com/STMicroelectronics/STM32CubeL4/blob/master/Drivers/STM32L4xx_HAL_Driver/Src/stm32l4xx_hal_flash.c). Assumed to still be Licensed by ST under BSD 3-Clause license, 
but the [license File is now blank](https://github.com/STMicroelectronics/STM32CubeL4/issues/63).  

Additional thanks to Elecia White (the Making Embedded Systems Instructor) for the code review, in particular to help find the cause of those nasty Hard Faults.
Also thanks to the class mentors Erin, Daniel, Thomas, and Jeff... as well as all my classmates on the discord channel. A lot of smart and creative people 
with all sorts of interesting ideas!
<br/><br/>

## Diagram(s) of the architecture

Show below is the basic diagram of the architecture. The network feature has not yet been implemented:

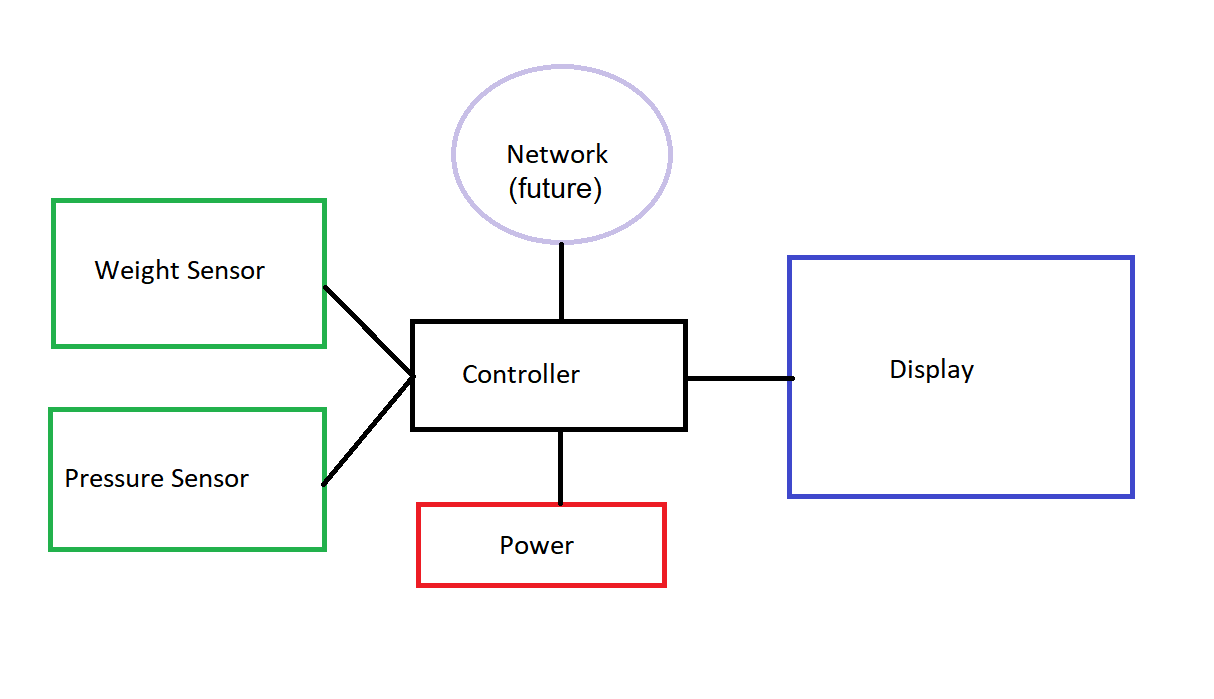
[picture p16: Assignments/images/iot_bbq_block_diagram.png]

<br/><br/>

## Build Instructions

There are two options for building: the GUI from Visual Studio and a command-line batch file, both on Windows.
<br/><br/>

#### Build in Visual Studio

Open the Visual Studio Solution File called [IoT_BBQ_STM32.sln](https://github.com/gojimmypi/IoT_BBQ/blob/main/IoT_BBQ_STM32/IoT_BBQ_STM32.sln). 
Find the `IoT_BBQ_STM32` Project. Right-click and select "Build...":

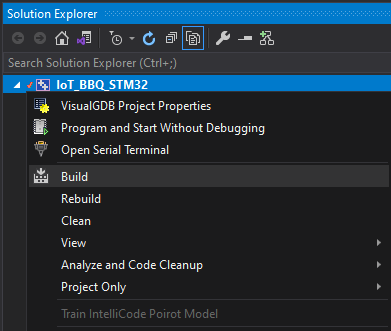
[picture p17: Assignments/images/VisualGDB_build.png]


To build and upload code, simply click the green `VisualGDB Debugger` button:



If the build was successful, the code will be sent to the board:

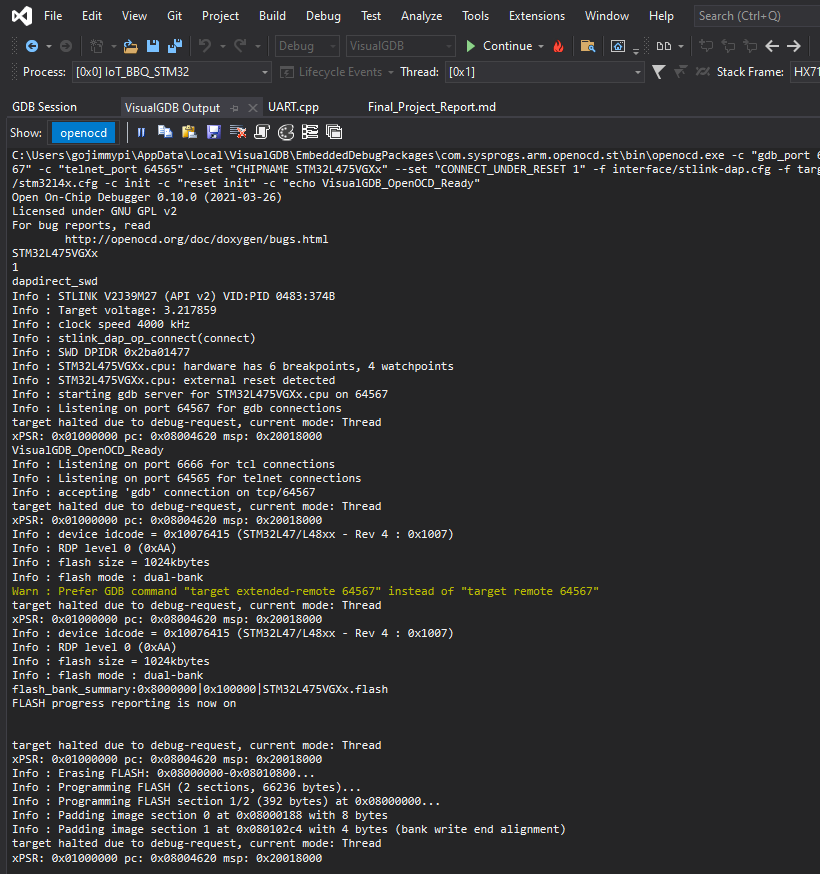
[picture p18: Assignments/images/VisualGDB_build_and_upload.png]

<br/><br/>

#### Build from Command-Line

If the STM32 toolchain is installed (for Windows) there's also an auto-generated [batch file](https://github.com/gojimmypi/IoT_BBQ/blob/main/IoT_BBQ_STM32/IoT_BBQ_STM32-Debug.bat) to build from command-line.

```

```

See also [Project Readme Build Instructions](https://github.com/gojimmypi/IoT_BBQ/tree/main/IoT_BBQ_STM32#build-from-a-batch-file)
<br/><br/>

### How to build the system (including the toolchain(s))

The only toolchain required for this project is the [VisualGDB Extension](https://visualgdb.com/). 
See the [Developing STM32 projects with Visual Studio](https://visualgdb.com/tutorials/arm/stm32/) walk-through.

These settings are included the project solution file but included here for reference:

Project Config Step 1:

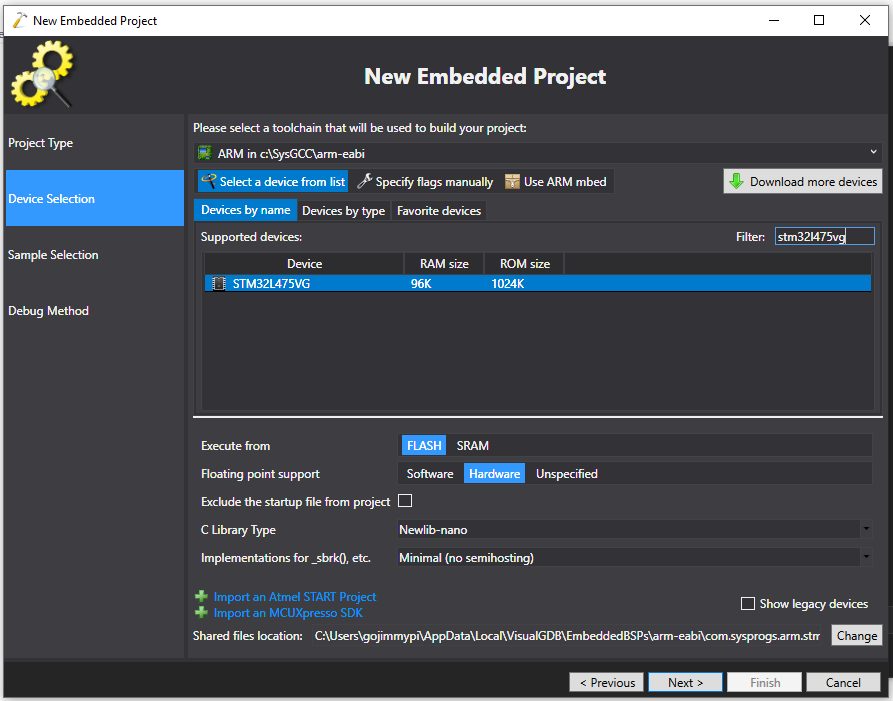
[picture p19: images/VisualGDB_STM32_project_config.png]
VisualGDB_STM32_project_config


Project Config Step 2:

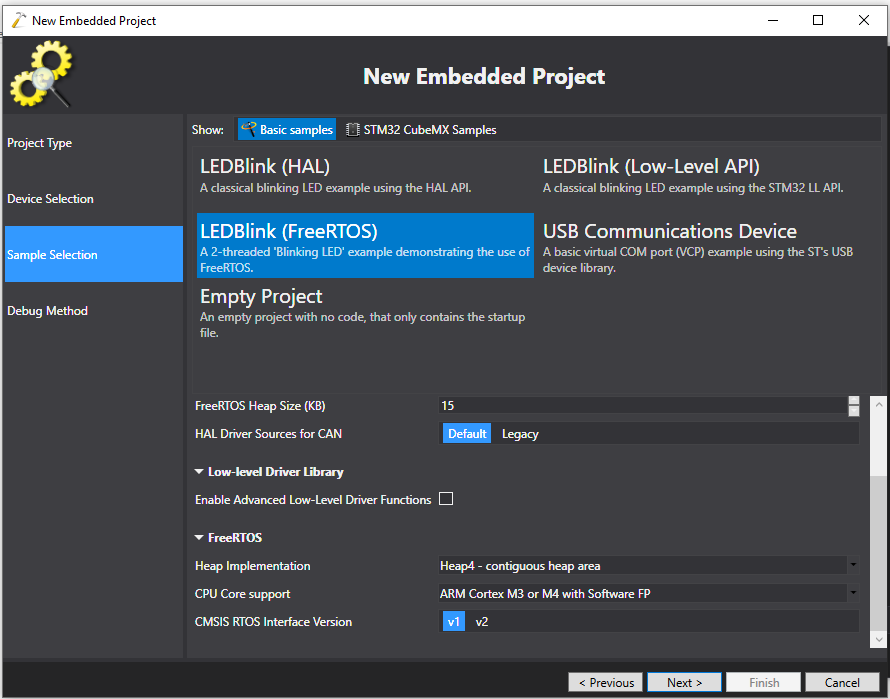
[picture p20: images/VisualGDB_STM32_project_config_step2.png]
VisualGDB_STM32_project_config_step2


Project Config Step 3:

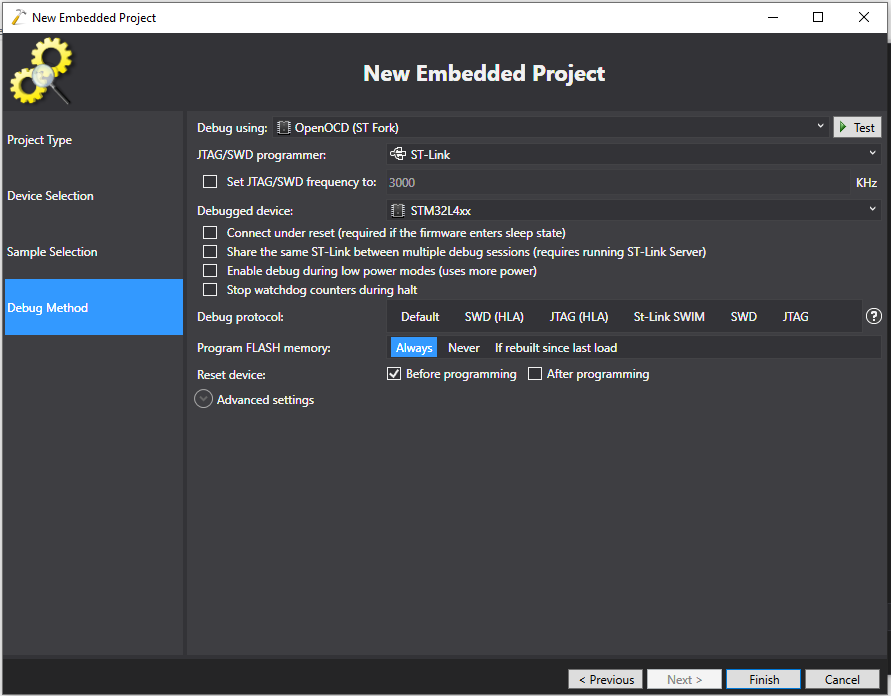
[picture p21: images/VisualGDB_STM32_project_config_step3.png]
VisualGDB_STM32_project_config_step3


See above for the [build instructions](https://github.com/gojimmypi/IoT_BBQ/blob/main/Assignments/Final_Project_Report.md#build-instructions).

<br/><br/>

### Hardware

- Mouser [ST B-L475E-IOT01A1](https://www.mouser.com/ProductDetail/stmicroelectronics/b-l475e-iot01a1/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)
- Amazon [SSD1306 I2C Serial](https://www.amazon.com/dp/B08KY21SR2/)
- Sparkfun [Load Cell Amplifier HX711](https://www.sparkfun.com/products/13879?_ga=2.84341273.1032917369.1645317851-1685161029.1637878826)
- Adafruit [Strain Gauge Load Cell - 4 Wires - 20Kg](https://www.adafruit.com/product/4543)

Hardware wiring diagram:

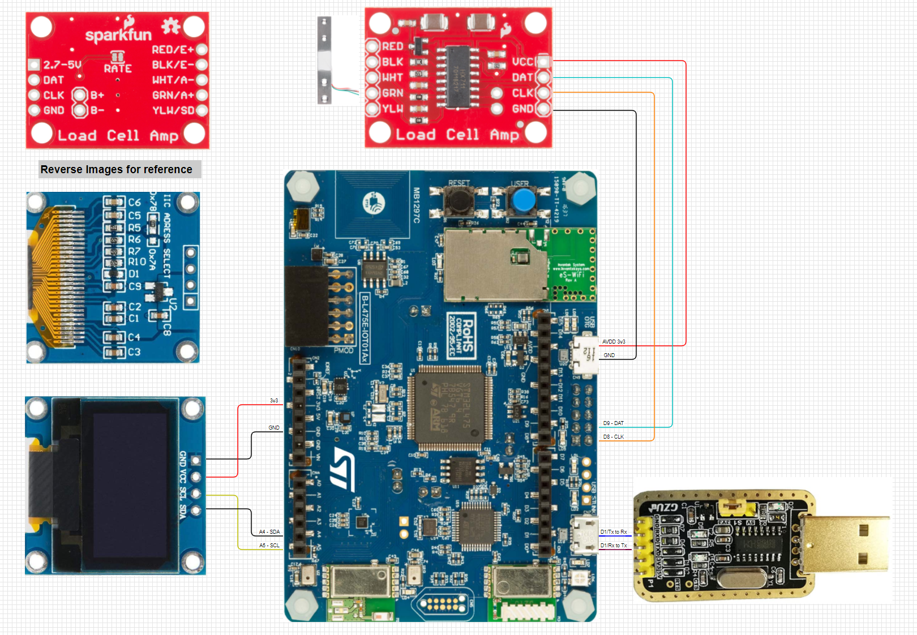
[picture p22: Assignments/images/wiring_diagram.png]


<br/><br/>

### Software

The source code can be downloaded from [GitHub gojimmypi/IoT_BBQ](https://github.com/gojimmypi/IoT_BBQ). The only other software needed is Visual Studio and
VisualGDB (and an internet connection, as VissualGDB will download and install toolchains and libraries as needed.) 

<br/><br/>

### How you debugged and tested the system

All of the development and debugging was completed in Visual Studio using breakpoints and the single-step-debugging features available from the VisualGDB extension.

Single-step inspection:

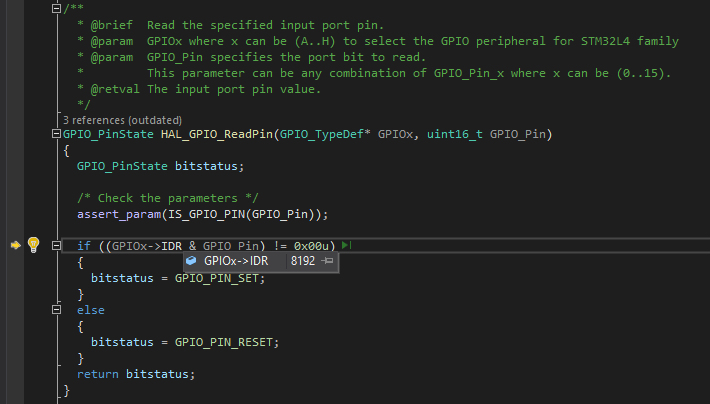
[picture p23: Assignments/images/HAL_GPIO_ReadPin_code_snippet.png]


Heap pointer check:

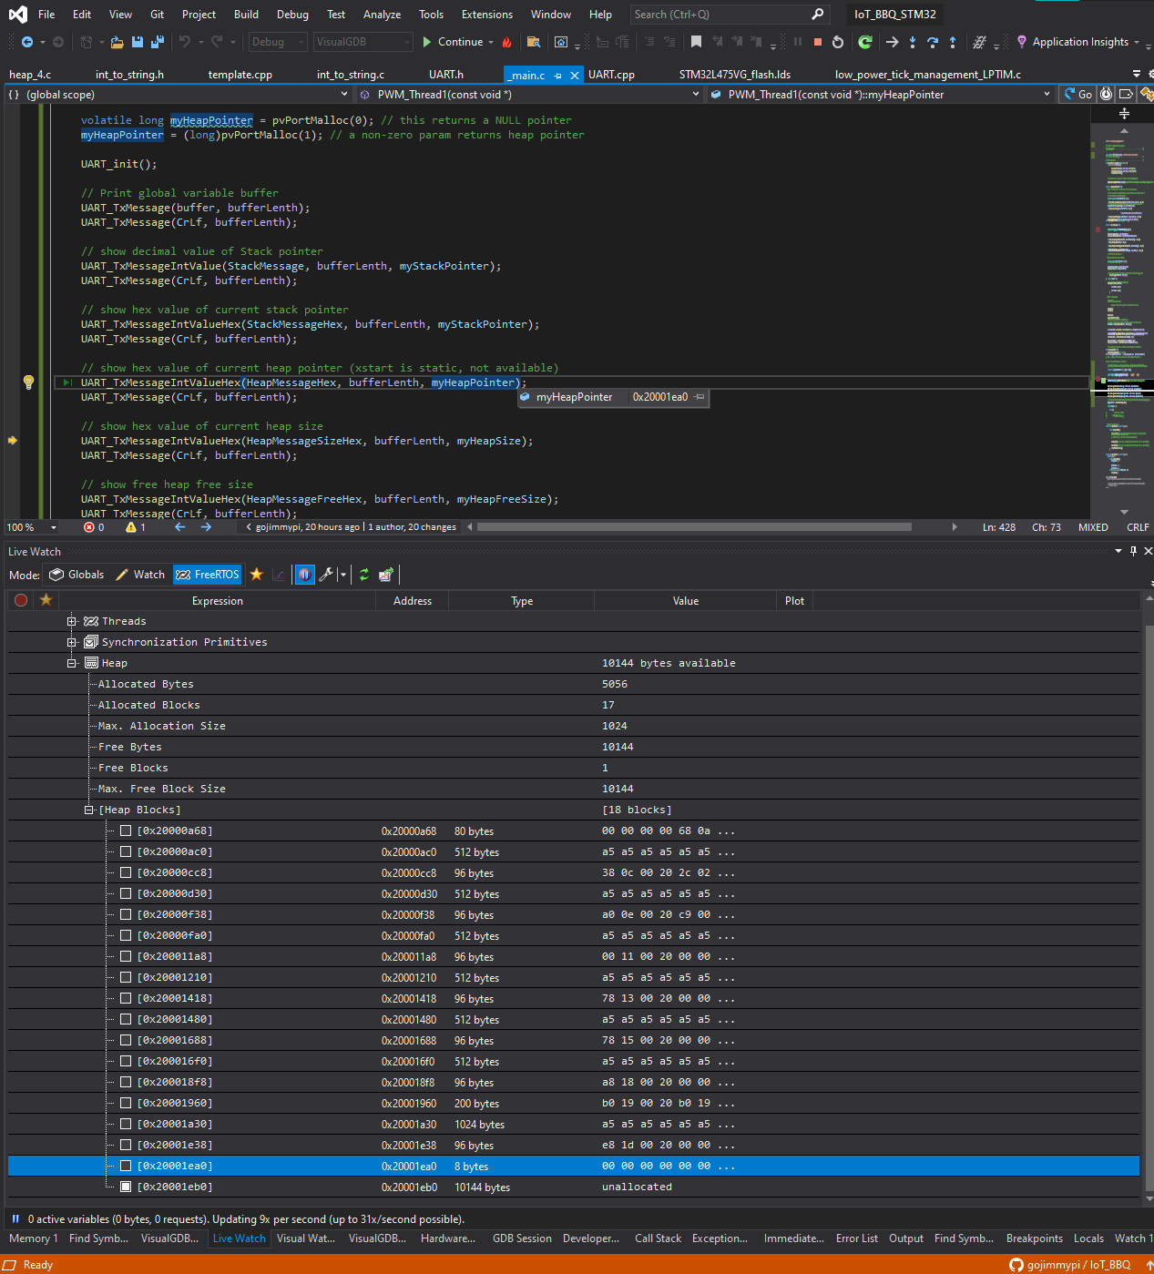
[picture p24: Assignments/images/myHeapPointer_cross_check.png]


Memory address inspection:

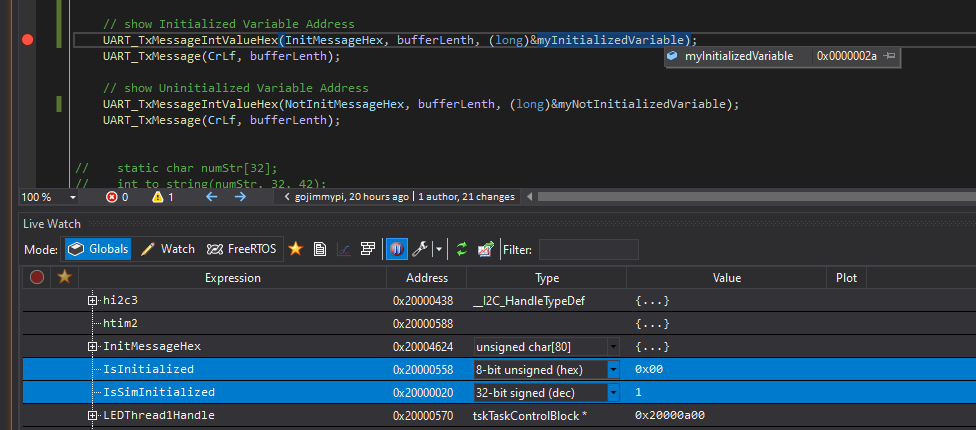
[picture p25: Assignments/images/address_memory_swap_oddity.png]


Breakpoints, code explorer, and other system monitoring features were quite helpful:

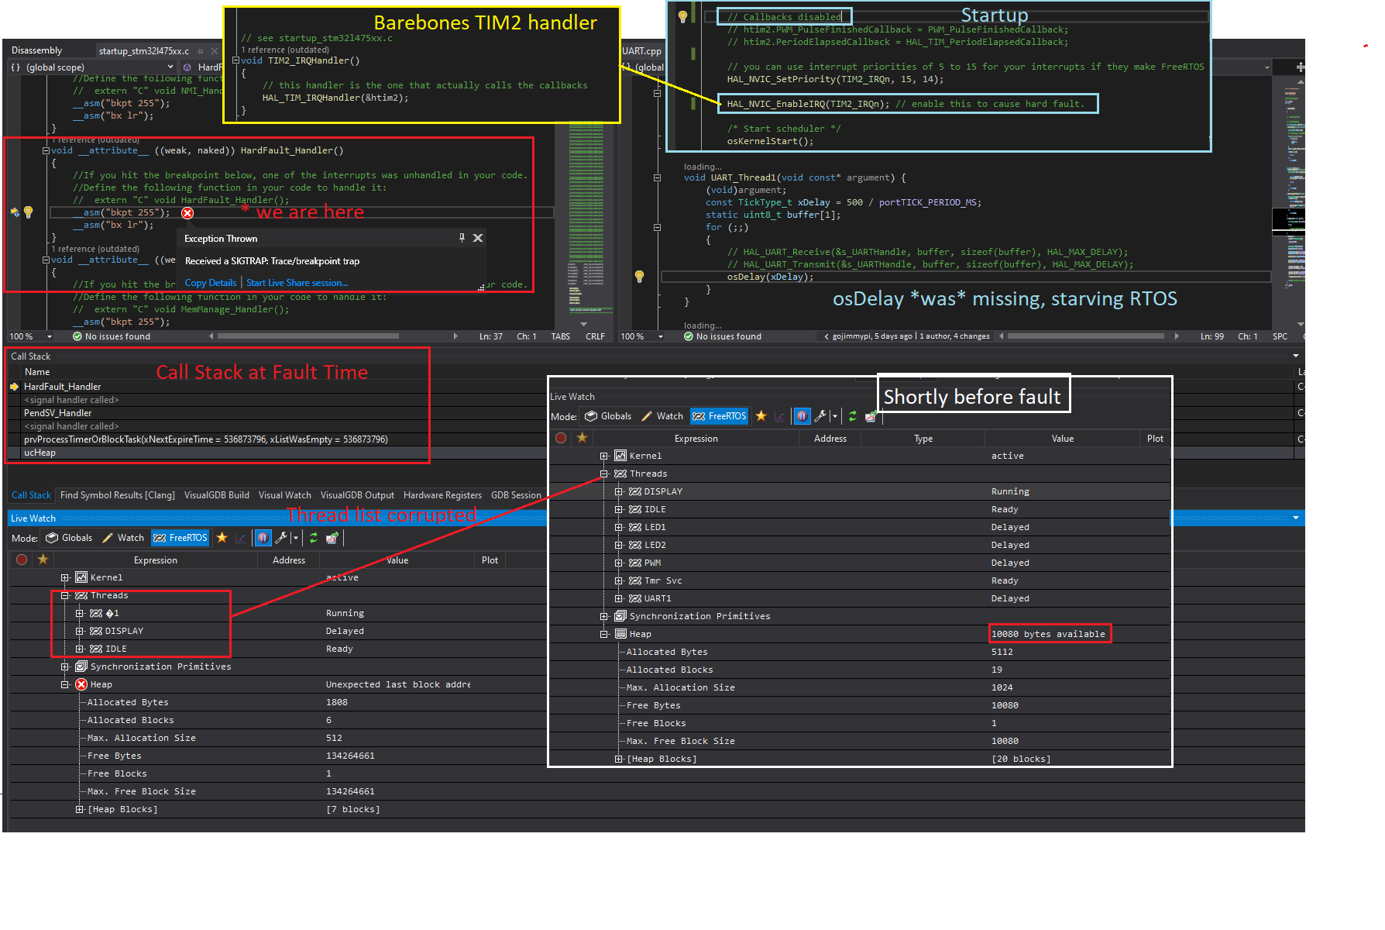
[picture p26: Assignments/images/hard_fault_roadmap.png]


<br/><br/>

## Future

Although the discovery board was convenient from a _getting started_ perspective, it is also massive and power hungry.
The next steps are to port this project to a [Blue Pill]().
<br/><br/>

## What would be needed to get this project ready for production?

Key to a production deployment would be an _enclosure_ and some way to have them mass-produced. For large-scale production, some means of
mass-programming the devices would be needed. It would not be practical to manually plug in a million boards and program them each one at a time.
<br/><br/>

## How would you extend this project to do something more? Are there other features you'd like? How would you go about adding them?

I chose this particular IoT Discovery board for the WiFi capabilities. As it turns out, the power consumption is simply way too high
for battery operation.  Our grill is located a bit far from the house; I certainly don't want to run an extension cord. 
I have some [LoRa experience](https://gojimmypi.github.io/tag/lora/) and plan to see if I can get that working with an MQTT server.

There are also plans for including a firebox temperature sensor, specifically the MAX6675 Module + K Type Thermocouple Temperature 
as described in the [original README](https://github.com/gojimmypi/IoT_BBQ/blob/main/README.md#iot_bbq) from a few years back 
when I created something for the ESP8266.
<br/><br/>

## Grading

Self assessment of the project: for each criteria, choose a score (1, 2, 3) and explain your reason for the score in 1-2 sentences.
Have you gone beyond the base requirements? How so?

| Criteria | 1 - Needs Improvement  | 2 - Meets Expectations | 3 - Exceeds Expectations |
| --- | --- | --- | --- |
| Project meets minimum project goals | | 2+ [Basic State Machine](https://github.com/gojimmypi/IoT_BBQ/blob/cc7372a3d11caf1aeab8de3807fefd8d7b27aa1b/IoT_BBQ_STM32/LED/LED.cpp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), additional sensors [LPS22HB](https://github.com/gojimmypi/IoT_BBQ/tree/main/IoT_BBQ_STM32/LPS22HB), [HX711](https://github.com/gojimmypi/IoT_BBQ/tree/main/IoT_BBQ_STM32/HX711), well documented. No serial commands | |
| Completeness of deliverables | | | Readable code, [each point addressed](https://github.com/gojimmypi/IoT_BBQ/blob/main/Assignments/Final_Project.md), [video](https://youtu.be/YIoqKTbCUQQ) |
| Clear intentions and working code | | 2+ System works as decribed | (docs not as professionally polished as I'd like) |
| Reusing code | | | [License summary](https://github.com/gojimmypi/IoT_BBQ/blob/main/Assignments/Final_Project_Report.md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) and [Build Info](https://github.com/gojimmypi/IoT_BBQ/blob/main/Assignments/Final_Project_Report.md#build-instructions) |
| Originality and scope of goals | | | This is clearly an awesome Propane Tank Weight Project! ;) The scope of goals was appropriately challenging yet reasonable for the class.  |
| Self-assessment (Mentor category only) | | n/a | |
| Bonus: Power analysis, firmware update, or system profiling | | | [Power Analysis](https://github.com/gojimmypi/IoT_BBQ/blob/main/Assignments/Final_Project.md#power-analysis) also  [shared on Twitter](https://twitter.com/gojimmypi/status/1492178884883746820?s=20&t=MRzHRuswJXuYwHc56WS9yQ) |
! Bonus: Version control was used.                               |                        |                                              | [hundreds of commits](https://github.com/gojimmypi/IoT_BBQ/commits/main)   |

* I created the video footage of the project in action on my phone and took all the pictures, but the final consolidated video was assembled and subtitled by someone else. Thank you!!!
<br/><br/>
 
See the Class Assignment [additional links](https://github.com/gojimmypi/IoT_BBQ/tree/main/Assignments#links) for other resources.

# Final Project Submission

See [Final Project Submission](./Final_Project_Submission.md)

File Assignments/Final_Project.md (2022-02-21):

# Final Project

This document addresses the [Final Project Instructions](./Final_Project_Instructions.md) for the [Making Embedded Systems](https://lms.classpert.com/classpert-x/courses/making-embedded-systems-wUXIUA) class.

The objective is to create Propane Tank Weight Sensor System with something considerably more accurate and precise to replace the stock mechanical spring gauge:

   
 
## Minimum Project Requirements
 
The project must:

### (a) Use a Cortex-M processor: 

This project is using an STMicro STML4, specifically the [STM32L475VG](https://www.st.com/resource/en/datasheet/stm32l475vg.pdf), 
part of the [STM32 Ultra Low Power](https://www.st.com/en/microcontrollers-microprocessors/stm32-ultra-low-power-mcus.html) Arm Cortex-M4 32-bit MCU+FPU series
found on the  [B-L475E-IOT01A Discovery Board](https://www.st.com/resource/en/user_manual/um2153-discovery-kit-for-iot-node-multichannel-communication-with-stm32l4-stmicroelectronics.pdf).

The prototype uses the [Discovery kit for IoT node](https://www.st.com/resource/en/user_manual/um2153-discovery-kit-for-iot-node-multichannel-communication-with-stm32l4-stmicroelectronics.pdf).

### (b) Have a button that causes an interrupt

This project leverages the code from [Exercise 4](./Exercise_4.md) that implements an operational mode/state switch via interrupt-driven button press code.
There's a small [button library](../IoT_BBQ_STM32/HX711/BUTTON/) as well as the [interrupt handler](../IoT_BBQ_STM32/_main_interrupt.c) that deals with 
button presses and system state changes.

### (c) Use at least three peripherals such as ADC, DAC, PWM LED, Smart LED, LCD, sensor, BLE

The peripherals used in the project:

#### External:

* Load cell (weight sensor) such as the [SparkFun HX711](https://www.sparkfun.com/products/13879). See [HX711 code](../IoT_BBQ_STM32/HX711/).

* Display: SSD1306 OLED Dual Color (Yellow / Blue) such as [this I2C Serial 12864 on Amazon](https://www.amazon.com/dp/B08KY21SR2/) that includes embedded Driver IC. See [SSD1306 code](../IoT_BBQ_STM32/SSD1306/)

* Temperature Sensor (The onboard device TODO specify)

#### Internal

* Onboard LED: See [LED code](../IoT_BBQ_STM32/LED/)

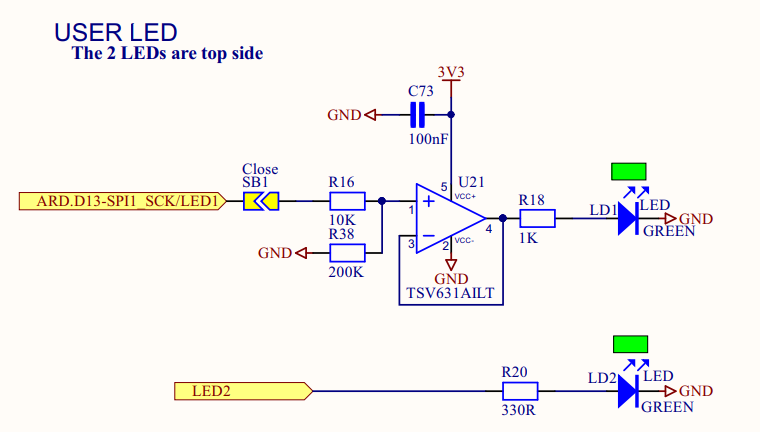
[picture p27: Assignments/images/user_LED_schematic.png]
user_LED_schematic


* The built-in STM32L475 Flash is used to save tare weight offset. (see [code](../IoT_BBQ_STM32/Flash/)). 
There's a [check for button long press](../IoT_BBQ_STM32/BUTTON/button.cpp)
in the [RTOS Display Thread](../IoT_BBQ_STM32/DISPLAY/DISPLAY.cpp), [here](https://github.com/gojimmypi/IoT_BBQ/blob/f53dc77e12903428f3710e6ed0a09f64ed9e8a7e/IoT_BBQ_STM32/DISPLAY/DISPLAY.cpp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). 
Upon detecting a button long press, the display thread is paused and a new system `Tare` state
is assigned. Upon [entering the Tare State](https://github.com/gojimmypi/IoT_BBQ/blob/c9316d246b56a14a15f69095f7e19a288091ab0c/IoT_BBQ_STM32/DISPLAY/DISPLAY.cpp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) 
the display is cleared, the message "Tare" is displayed, and the calculated [offset](https://github.com/gojimmypi/IoT_BBQ/blob/c9316d246b56a14a15f69095f7e19a288091ab0c/IoT_BBQ_STM32/HX711/HX711.cpp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) 
is [saved to flash via SaveDeviceConfig()](https://github.com/gojimmypi/IoT_BBQ/blob/c9316d246b56a14a15f69095f7e19a288091ab0c/IoT_BBQ_STM32/Flash/flash_config.c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) 
from the [DoScaleTare() task](https://github.com/gojimmypi/IoT_BBQ/blob/c9316d246b56a14a15f69095f7e19a288091ab0c/IoT_BBQ_STM32/Tasks/task_weight_monitor.cpp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).

See the [customized linker file](https://github.com/gojimmypi/IoT_BBQ/blob/16c2e625e0a9bc0637c29e78947d009f5d849b26/IoT_BBQ_STM32/STM32L475VG_flash.lds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)
that placed Flash memory starting at `FDATA` = `0x080FF000`

```
MEMORY
{
	FLASH (RX) : ORIGIN = 0x08000000, LENGTH = 996K
	FDATA (R)  : ORIGIN = 0x080FF000, LENGTH = 4K
	SRAM (RWX) : ORIGIN = 0x20000000, LENGTH = 96K
	RAM2 (RWX) : ORIGIN = 0x10000000, LENGTH = 32K
}
```
The Flash configuration is mapped to the [static const struct FlashConfig FLASH_CONFIG](https://github.com/gojimmypi/IoT_BBQ/blob/16c2e625e0a9bc0637c29e78947d009f5d849b26/IoT_BBQ_STM32/Flash/flash_config.c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)
in Flash memory, along with a copy in an updatable RAM cache value:

```
    // FLASH_CONFIG is the data actually on the flash. See DeviceFlashConfig()
    __attribute__((__section__(".flash_user_data"))) static const struct FlashConfig FLASH_CONFIG;

    // CACHE_CONFIG is the runtime, updatable copy of the config. See DeviceCacheConfig()
    static struct FlashConfig CACHE_CONFIG;
```

* The on-board [LPS22HB barometric sensor](https://www.st.com/en/mems-and-sensors/lps22hb.html) was used in this project (see [code](../IoT_BBQ_STM32/LPS22HB/README.md)).
Currently the pressure reading is sent to the UART in the [RTOS LED Thread #11](../IoT_BBQ_STM32/_main_LED_Thread1.c). To make things interesting from a
multi-threaded RTOS perspective, the pressure is also read in the experimental [PWM Thread](../IoT_BBQ_STM32/_main_pwm_thread.c). 

* PWM Timers and watchdogs

There are some experiments with STM32 PWM in the [PWM Thread](../IoT_BBQ_STM32/_main_pwm_thread.c), but this was done only for educational purposes
and will be removed from the final project.

See Page 44 of the [STM32L475xx Datasheet (DS10969)](https://www.st.com/resource/en/datasheet/stm32l475vg.pdf):

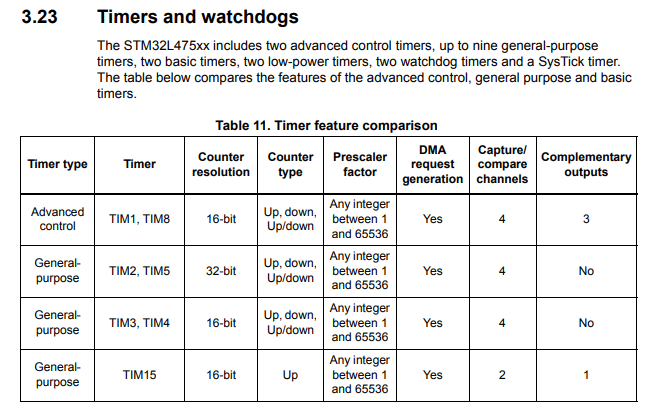
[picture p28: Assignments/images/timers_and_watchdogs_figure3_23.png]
timers_and_watchdogs_figure3_23


### (d) Have serial port output

See  [UART code](../IoT_BBQ_STM32/UART/). Several of the RTOS threads send data to the UART, 
including the [main LED Thread1](https://github.com/gojimmypi/IoT_BBQ/blob/200882b131afad40577f094373feec7bd9153e3a/IoT_BBQ_STM32/_main_LED_Thread1.c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)
and the [experimental PWN Thread](https://github.com/gojimmypi/IoT_BBQ/blob/200882b131afad40577f094373feec7bd9153e3a/IoT_BBQ_STM32/_main_pwm_thread.c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).

An [RTOS-safe semaphore wrapper](https://github.com/gojimmypi/IoT_BBQ/blob/200882b131afad40577f094373feec7bd9153e3a/IoT_BBQ_STM32/UART/UART.cpp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) 
was created around the `HAL_UART_Transmit` 
found in the [STMicroelectronics / stm32l4xx_hal_driver / stm32l4xx_hal_uart.c](https://github.com/STMicroelectronics/stm32l4xx_hal_driver/blob/master/Src/stm32l4xx_hal_uart.c).

Sample UART output at startup:

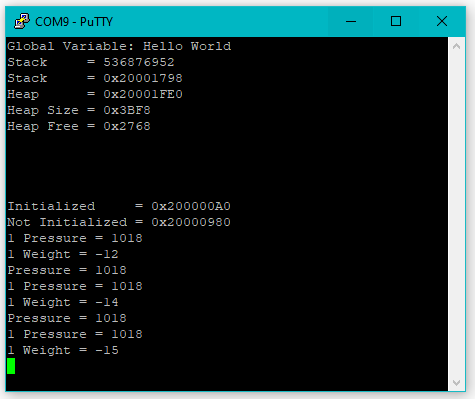
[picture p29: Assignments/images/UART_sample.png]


### (e) Implement an algorithmic piece that makes the system interesting

> _Every sensor is a temperature sensor. Some are better than others._ --[Unknown / Elecia White](https://electronics.stackexchange.com/questions/386691/who-said-all-sensors-are-temperature-sensors-but-some-are-better-than-others)

Consider measuring weight over time and temperature. 

TODO: _interesting_

### (f) Implement a state machine

There's currently a prototype [LED State Machine](https://github.com/gojimmypi/IoT_BBQ/blob/ce44c00152af0a16b26d9a246a799ed7db8553ae/IoT_BBQ_STM32/LED/LED.cpp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) 
with [IsBlinking, AlwaysOn, AlwaysOff](https://github.com/gojimmypi/IoT_BBQ/blob/ce44c00152af0a16b26d9a246a799ed7db8553ae/IoT_BBQ_STM32/LED/LED.h#L14) states.

### Not required to use a HAL (but it is encouraged)

This project uses the [STM32L4XX HAL](https://github.com/STMicroelectronics/stm32l4xx_hal_driver), 
for example [here](https://github.com/gojimmypi/IoT_BBQ/blob/ce44c00152af0a16b26d9a246a799ed7db8553ae/IoT_BBQ_STM32/_main.c#L2), 
and is a multi-threaded application using embedded RTOS (specfically [CMSIS_RTOS](https://arm-software.github.io/CMSIS_5/RTOS2/html/rtos_api2.html)) for example included [here](https://github.com/gojimmypi/IoT_BBQ/blob/ce44c00152af0a16b26d9a246a799ed7db8553ae/IoT_BBQ_STM32/_main.c#L3).

Code that uses the STM32 HAL will need the `#include <stm32l4xx_hal.h>`. Future versions of this codebase should include a hardware conditional include such as [this](https://github.com/gojimmypi/IoT_BBQ/blob/314d03bb8053d09c3730533c384fd499d35e3231/IoT_BBQ_STM32/SSD1306/ssd1306.h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) example:

```
#if defined(STM32F0)
#include "stm32f0xx_hal.h"
#elif defined(STM32F1)
#include "stm32f1xx_hal.h"
#elif defined(STM32F4)
#include "stm32f4xx_hal.h"
#include "stm32f4xx_hal_gpio.h"
#elif defined(STM32L0)
#include "stm32l0xx_hal.h"
#elif defined(STM32L1)
#include "stm32l1xx_hal.h"
#elif defined(STM32L4)
#include "stm32l4xx_hal.h"
#elif defined(STM32F3)
#include "stm32f3xx_hal.h"
#elif defined(STM32H7)
#include "stm32h7xx_hal.h"
#elif defined(STM32F7)
#include "stm32f7xx_hal.h"
#elif defined(STM32G0)
#include "stm32g0xx_hal.h"
#elif defined(STM32G4)
#include "stm32g4xx_hal.h"
#else
#error "Hardware platform not supported."
#endif
```

## List of the tasks to complete for the project

- [X] Confirm operational display
- [X] Confirm operational weight sensor
- [X] Show weight value on display
- [ ] Update docs on new I2C port being used for SSD1306
- [X] Confirm serial port operation
- [X] Implement Serial Rx/Tx
- [X] Implement serial debug messages
- [ ] Sleep serial port when inactive
- [ ] Implement Sleep / Wake-up
- [ ] Determine field power source
- [X] Design enclosure
- [ ] Print enclosure
- [ ] Mount hardware in enclosure

## Challenges

There are plenty of potential challenges. This project was originally started (and abandoned) [6 years ago](https://github.com/gojimmypi/IoT_BBQ/tree/c15d7c90c0f49ad006a91550d2dd1ab7d34544e8), in part due to 
mechanical issues. It is hoped that modern 3D Printing flexibility will be able to help with the mechanical mounting aspects.

Technical implementation difficulties of a new hardware platform are always a concern (the original project was based on the ESP8266 and the LUA language).

Details on some of the challenges:

### Minimal Example Code

There is currently relatively little [STM32CubeL4 example code for the B-L475E-IOT01A discovery board](https://github.com/STMicroelectronics/STM32CubeL4/tree/master/Projects/B-L475E-IOT01A/Examples) chosen for this project. 
Porting code between architectures is beyond the scope of the class.

Furthermore, the HX711 weight sensor interface and SSD1306 display are not built-in on the development board. 

### Mistakes in Example Code

I submitted [STM32CubeL4/issues/61](https://github.com/STMicroelectronics/STM32CubeL4/issues/61) and [PR #60](https://github.com/STMicroelectronics/STM32CubeL4/pull/60) 
to fix a problem in an example where there Source Address was the same as the Destination. (not only uninteresting, but failed with error)

### External sensors and peripherals

Certainly one of the benefits of having an evaluation board is having the connections "built-in" and sample code readily available. Unfortunately the Discovery Board used did not have a display and the I2C HX711 load cell was of course external, 
adding the additional challenge of finding and wiring up the I2C connections.

The better part of a day was spent trying to get the SSD1306 Display to work on `I2C1` that the [documentation](https://www.st.com/resource/en/user_manual/um2153-discovery-kit-for-iot-node-multichannel-communication-with-stm32l4-stmicroelectronics.pdf) claims is on `PB8` and `PB9`,
but it was later learned the STM32CubeIDE shows GPIO pins `PB6` and `PB7` instead:

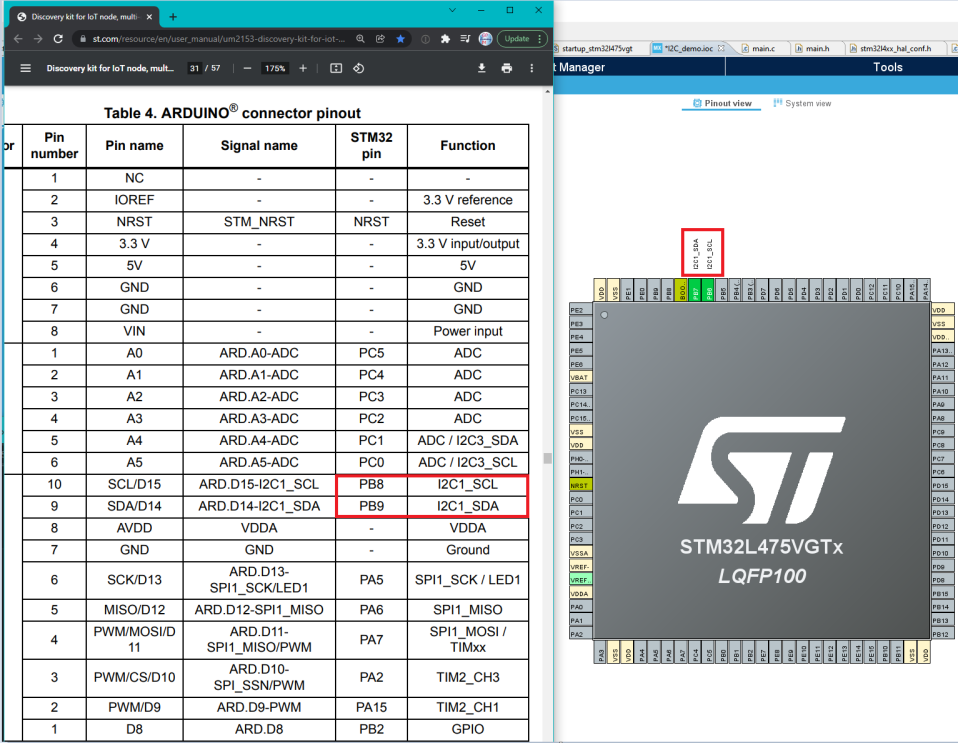
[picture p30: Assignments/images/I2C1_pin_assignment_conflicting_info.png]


This closeup from the STM32CubeIDE clearly indicates `I2C1` GPIO pins are on `PB6` and `PB7`.

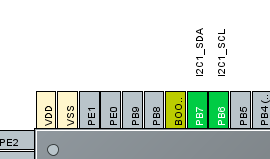
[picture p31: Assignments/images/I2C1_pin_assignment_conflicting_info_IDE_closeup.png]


The [SSD31306 configuration](../IoT_BBQ_STM32/SSD1306/ssd1306_conf.h) is currently using `I2C3` instead. (See also the [SSD1306 default template](../IoT_BBQ_STM32/SSD1306/ssd1306_conf_template.h))

Lesson learned: always do a simple IO level and control check on GPIO lines before starting something more complex such as I2C communication.

### Known library Problems

There's an [open STMicroelectronics/stm32l0xx_hal_driver issue: An I2C NACK during memory address transfer goes undetected](https://github.com/STMicroelectronics/stm32l0xx_hal_driver/issues/3) to be aware of that may impact I2C. 
This was stumbled upon when encountering a `I2C_WaitOnFlagUntilTimeout` problem, but that was related to the GPIO pin conflict, described above.

### Mechanical support for weight sensor

I [reached out on Twitter](https://twitter.com/gojimmypi/status/1481711080497823744?s=20) for suggestions on how to mount the load cell. 
One of the responses is regarding [load cell damage if the propane tank is dropped into place](https://twitter.com/RueNahcMohr/status/1481724026221305861?s=20).

Another concern is [load cell creep](https://twitter.com/GMahovlic/status/1481724848040775685?s=20) when the tank is left in place for a long period. 

There's no mention of "load creep" in the [Avia Semicondictor HX711 Datasheet](https://cdn.sparkfun.com/assets/b/f/5/a/e/hx711F_EN.pdf), but that seems like a legitimate concern. There is only
one instance of the word "creep" on the [Sparkfun Load Cell Amplifier HX711 Breakout Hookup Guide](https://learn.sparkfun.com/tutorials/load-cell-amplifier-hx711-breakout-hookup-guide/all).

Yet another potential challenge pointed out on Twitter is the [temperaturer drift over time](https://twitter.com/ioPush_net/status/1481762159851974660?s=20) of the load cell.

### Physical Room

There's relatively limited room for the tank: so little, that there's a hole in the bottom of the cabinet to help with maneuvering when replacing a fresh tank:

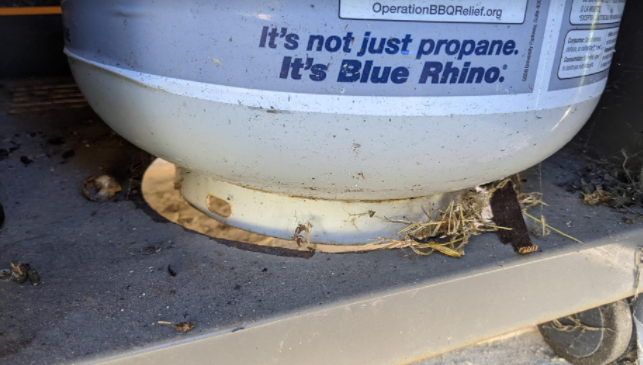
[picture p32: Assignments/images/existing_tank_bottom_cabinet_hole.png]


### Enclosure

Enclosures are always challenging. Fortunately there's a 3D Printer available to create a custom enclosure for this project.

The enclosure should probably be weather-proof, and located reasonably far from the grill heat box which can get up to 500 degrees.

The OLED display is likely not tolerant to hard freeze. 

### Component Availability

If any sort of mass-production was desired, there's of course the chip shortage to be concerned about.

### Hard Faults

Any list of challenges would not be complete without of course my Hard Faults! 



## Deliverables

The final project will be delivered as:

(a) Video of the system working as intended. See [https://youtu.be/YIoqKTbCUQQ](https://youtu.be/YIoqKTbCUQQ)

(b) Write up of the system (PDF or Google docs report). This document and [Final Project Report](./Final_Project_Report.md). There's also a [Final Propect Report PDF](./Final_Project_Report.pdf) and [Final Propject PDF](./Final_Project.pdf) .

(c) Link to the code: see [GitHub IoT BBQ STM32 Project](https://github.com/gojimmypi/IoT_BBQ/tree/main/IoT_BBQ_STM32).

Instructions to build can be found in the [solution directory README](../IoT_BBQ_STM32/README.md)

## Optional Bonus

### Power analysis

Tips learned from Ben in class:

- When powering an embedded device from batteries, say a couple of AA cells, there's likely a voltage drop / fluctuation depending on what
the processor is doing at any given moment, that may affect things like ADC.

See also the [PPK2 Power Analysis Setup Notes(https://gojimmypi.github.io/ppk2-power-analysis/).

### Firmware update

TODO

### System profiling

TODO

The Power LED is always on, and needs to be unsoldered to not use it:

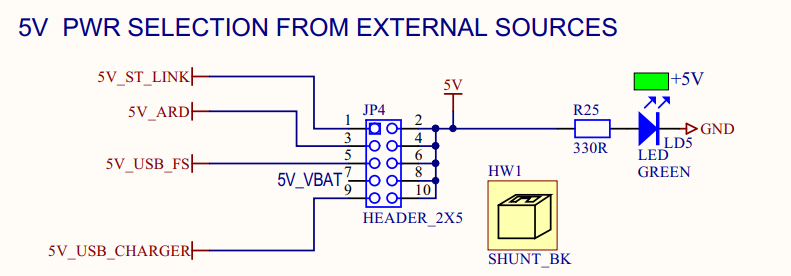
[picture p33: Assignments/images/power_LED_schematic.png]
power_LED_schematic


## References

### Mechanical

- Wikipedia [Propane](https://en.wikipedia.org/wiki/Propane)
- Statasys Grabcad Community [Propane Tank](https://grabcad.com/library/propane-tank)

### Core Hardware

- [STM32 Discovery Kits](https://www.st.com/en/evaluation-tools/stm32-discovery-kits.html#products)
- [STM32L4 series of ultra-low-power MCUs](https://www.st.com/en/microcontrollers-microprocessors/stm32l4-series.html)
- [ARM MBED DISCO-L475VG-IOT01A (B-L475E-IOT01A](https://os.mbed.com/platforms/ST-Discovery-L475E-IOT01A/) (this is where the link on the OTG file points)
- [Mouser 5 page B-L475E-IOT01A Data Brief ](https://www.mouser.com/datasheet/2/389/b-l475e-iot01a-1848022.pdf)
- [Mouser Discovery Kit for IoT Node](https://www.mouser.com/pdfdocs/RS7706_IC_STM32L475E-IOT01A1_0517d.pdf) (this is the front and back of the insert card in for the shipped product)
- [Mouser STMicroelectronics B-L475E-IOT01A Discovery Kit for IoT Node](https://www.mouser.com/new/stmicroelectronics/stm-b-l475e-iot01a-kit/)

### Drivers

- [ST-LINK, ST-LINK/V2, ST-LINK/V2-1, STLINK-V3 USB driver signed for Windows7, Windows8, Windows10](https://www.st.com/content/my_st_com/en/products/development-tools/software-development-tools/stm32-software-development-tools/stm32-utilities/stsw-link009.license=1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)

### Peripheral Hardware

- [SSD1306 I2C Serial](https://www.amazon.com/dp/B08KY21SR2/)
- [Sparkfun Load Cell Amplifier HX711 Breakout Hookup Guide](https://learn.sparkfun.com/tutorials/load-cell-amplifier-hx711-breakout-hookup-guide/all)
- [bogde/HX711](https://github.com/bogde/HX711)
- [nimaltd/HX711](https://github.com/nimaltd/HX711/blob/master/hx711.c)

### Development Environment

- Microsoft [Visual Studio 2019](https://docs.microsoft.com/en-us/visualstudio/releases/2019/release-notes)
- Sysprogs [VisualGDB Extension](https://visualgdb.com/)
- [CMSIS-RTOS2](https://arm-software.github.io/CMSIS_5/RTOS2/html/index.html)
- ST [STM32L4 Discovery kit IoT node software](https://www.st.com/en/evaluation-tools/b-l475e-iot01a.html#tools-software)
- ST [STM32CubeMX STM32Cube initialization code generator](https://www.st.com/en/development-tools/stm32cubemx.html#get-software)
- ST [STM32Cube MCU Package for STM32L4 series and STM32L4 Plus series (HAL, Low-Layer APIs and CMSIS, USB, TouchSensing, File system, RTOS)](https://www.st.com/en/embedded-software/stm32cubel4.html#tools-software)
- ST [Description of STM32L4/L4+ HAL and low-layer drivers - UM1884](https://www.st.com/resource/en/user_manual/dm00173145-description-of-stm32l4l4-hal-and-lowlayer-drivers-stmicroelectronics.pdf)

### Tutorials and Sample Code

- Sysprogs VisualGDB [Developing STM32 projects with Visual Studio tutorial](https://visualgdb.com/tutorials/arm/stm32/)
- Sysprogs VisualGDB [Using the STM32 UART interface with HAL](https://visualgdb.com/tutorials/arm/stm32/uart/hal/)
- Sysprogs VisualGDB [Using the I2C Interface on the STM32 Devices](https://visualgdb.com/tutorials/arm/stm32/i2c/)
- Sysprogs VisualGDB [Creating Advanced STM32CubeMX-based Projects with VisualGDB](https://visualgdb.com/tutorials/arm/stm32/cube/advanced/)
- Sysprogs VisualGDB [Controlling STM32 Hardware Timers using HAL](https://visualgdb.com/tutorials/arm/stm32/timers/hal/)
- Sysprogs VisualGDB [Using STM32 timers in PWM mode](https://visualgdb.com/tutorials/arm/stm32/pwm/)
- NordicPlayground [mbed stm32f4xx_hal_uart](https://github.com/NordicPlayground/mbed/blob/master/libraries/mbed/targets/cmsis/TARGET_STM/TARGET_DISCO_F407VG/stm32f4xx_hal_uart.c)
- [afiskon/stm32-ssd1306 example](https://github.com/afiskon/stm32-ssd1306/blob/master/examples/oled-tester/firmware/i2c/Src/main.c); The [code](https://github.com/afiskon/stm32-ssd1306/tree/master/ssd1306) is [included in this project](../IoT_BBQ_STM32/SSD1306/).
- [Sensors STM32CubeL4/Drivers/BSP/B-L475E-IOT01/](https://github.com/STMicroelectronics/STM32CubeL4/tree/master/Drivers/BSP/B-L475E-IOT01)
- github [akospasztor/stm32-bootloader](https://github.com/akospasztor/stm32-bootloader)

### Video Tutorials

- [Digi-Key Getting Started with STM32 - Timers and Timer Interrupts](https://www.digikey.com/en/maker/projects/getting-started-with-stm32-timers-and-timer-interrupts/d08e6493cefa486fb1e79c43c0b08cc6) by [Shawn Hymel](https://www.digikey.com/en/maker/profiles/72825bdd887a427eaf8d960b6505adac)
- [STMicroelectronics STM32CubeIDE basics - 05 TIM PWM HAL lab](https://www.youtube.com/watch?v=-AFCcfzK9xc)

### Programming

- [AVR035: Efficient C Coding for AVR](https://ww1.microchip.com/downloads/en/Appnotes/doc1497.pdf)

### Coding Standards

- Wayback Machine [GSFC C/C++ Coding Standards](http://web.archive.org/web/20090412090730/http://software.gsfc.nasa.gov/assetsbytype.cfm?TypeAsset=Standard) NASA Goddard Space Flight Center

### Cloud Demo
- [AWS AWS Cloud demonstration](https://github.com/STMicroelectronics/STM32CubeL4/tree/master/Projects/B-L475E-IOT01A/Demonstrations)

### Utilities

- [VS Code Extension: Markdown PDF](https://marketplace.visualstudio.com/items?itemName=yzane.markdown-pdf)

### Other Related Projects

- [Honeybee Hive Monitoring](https://hackaday.io/project/1741-honeybee-hive-monitoring) - also uses HX711
- [logicalelegance/midifun](https://github.com/logicalelegance/midifun/tree/master/Core) - sample project naming, directories, organziation.

# Final Project Submission

See [Final Project Submission](./Final_Project_Submission.md)

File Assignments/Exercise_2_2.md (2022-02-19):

# Read Mbed Code, Make Diagram

Exercise 2.2 for [Making Embedded Systems](https://lms.classpert.com/classpertx/courses/making-embedded-systems/cohort) class. 

Read mbed code, make diagram
- Create a sign in and log into the mbed compiler
- Go to mbed platforms https://os.mbed.com/platforms/
- Select any platform (hint: search for a processor similar to the one you are considering
for your final project)

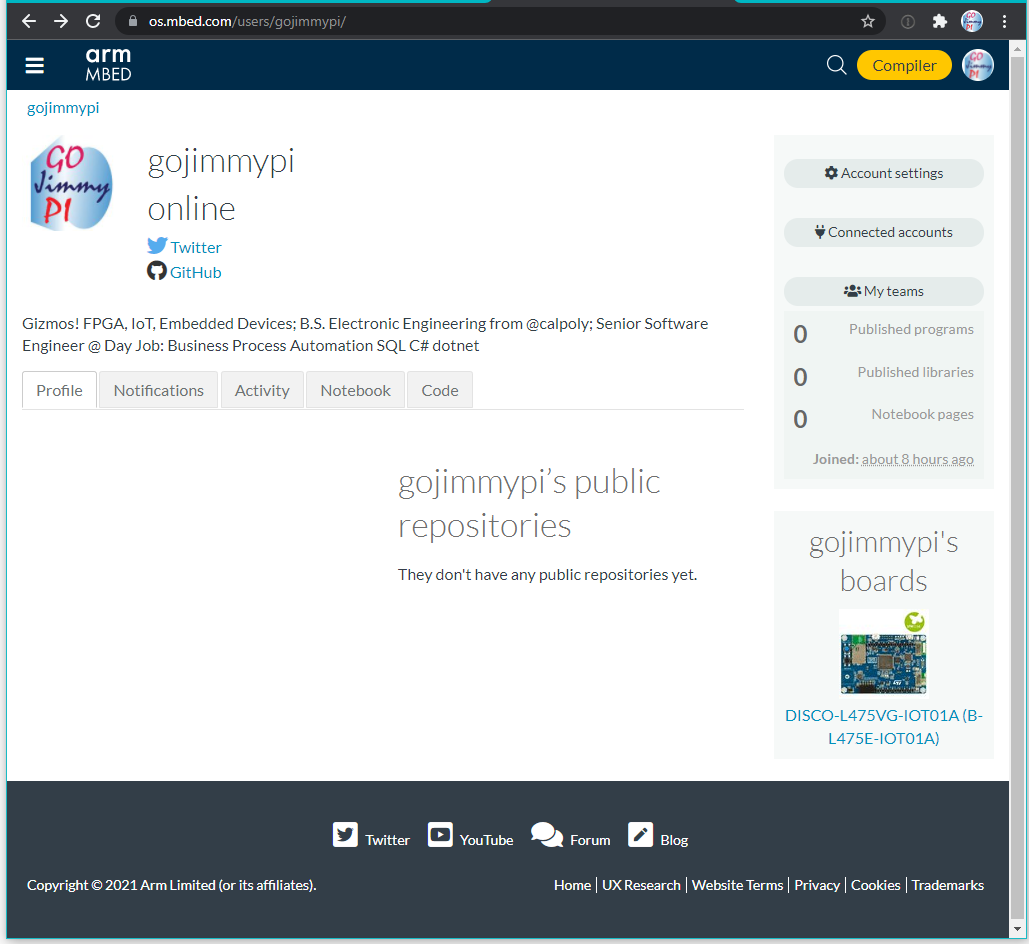
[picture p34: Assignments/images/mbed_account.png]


- Read through the platform page
- Add to Mbed Compiler (button on right)
- Load a simple sounding template



- Create a block diagram for this program, briefly explain why you chose the platform
and template you did, be prepared to talk about this board in Live Class



I chose the STM32L4 Discovery kit IoT node: [DISCO-L475VG-IOT01A (B-L475E-IOT01A)](https://os.mbed.com/platforms/ST-Discovery-L475E-IOT01A/)
for this class as it has a wide selection of built-in perihperals, and more importantly: plenty of _sample code_.

<< [Exercise 2.1](./Exercise_2_1.md) -- [Assignments](./README.md) -- [Exercise 3a](./Exercise_3a.md)

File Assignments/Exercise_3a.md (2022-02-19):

#Investigate project board

Exercise 3a for [Making Embedded Systems](https://lms.classpert.com/classpertx/courses/making-embedded-systems/cohort) class. 

Look at the documents for the board you are considering for your final project (or any 
[ST Discovery Board](https://www.st.com/en/evaluation-tools/stm32-discovery-kits.html#products)), draw the hardware block diagram for the board. For peripherals, note the
communication paths (SPI, I2C, etc).



The board I am using is the [B-L475E-IOT01A1](https://www.mouser.com/ProductDetail/STMicroelectronics/B-L475E-IOT01A1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), 

## Look at the [datasheet](https://www.mouser.com/datasheet/2/389/b-l475e-iot01a-1848022.pdf) for the processor and other documents. Answer these questions:

### What kind of processor is it?

The processor is the [STM32L475VG](https://www.st.com/resource/en/datasheet/stm32l475vg.pdf), part of the [STM32 Ultra Low Power](https://www.st.com/en/microcontrollers-microprocessors/stm32-ultra-low-power-mcus.html)
Arm® Cortex®-M4 32-bit MCU+FPU, 100DMIPS, USB OTG FS, analog, audio

### How much Flash and RAM does it have? Any other memory types?
up to 1MB Flash, 128 KB SRAM, USB OTG FS.

### Does it have any special peripherals? (List 3-5 that you noted as being interesting.)
20x communication interfaces! Including:

- USB OTG 2.0 full-speed
- 3x I2C
- 3x SPIs (and 1x Quad SPI)

### Does it have a floating point unit?
yes, this chip has 32-bit MCU + FPU 

### If it has an ADC, what are the features?
Rich analog peripherals (independent supply)
– 3x 12-bit ADC 5 Msps, up to 16-bit with hardware oversampling, 200 µA/Msps
– 2x 12-bit DAC output channels, low-power sample and hold
– 2x operational amplifiers with built

Look at one [application note](https://www.st.com/en/microcontrollers-microprocessors/stm32l475vg.html#documentation) for this processor.

[AN5012 Analog-to-digital audio conversion example using STM32L4 Series microcontroller peripherals](https://www.st.com/resource/en/application_note/an5012-analogtodigital-audio-conversion-example-using-stm32l4-series-microcontroller-peripherals-stmicroelectronics.p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)

<< [Exercise 2.2](./Exercise_2_2.md) -- [Assignments](./README.md) --  [Exercise 3b](./Exercise_3b.md)

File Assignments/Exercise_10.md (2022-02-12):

# Power Analysis

The worksheet describing Wordy’s power use is demonstrated in the lecture. Make one for your
system (either design or engineering version).

Estimates are ok in place of real numbers. If you have many components, limit it to the top 5-8
most likely to consume power. Even if you have a USB or wall powered system, identify the
largest consumers of power and how you might reduce power consumption.

Turn in a link to your power worksheet to Discord #assignment-submission by 9am on Feb 13th.

## Overview:

> "_only ST-LINK circuit has the power before USB enumeration, because the host PC only provides 100 mA to the board at that time. During the USB enumeration_"
-- [UM2153](https://www.st.com/resource/en/user_manual/um2153-discovery-kit-for-iot-node-multichannel-communication-with-stm32l4-stmicroelectronics.pdf) section 7.4 Power supply.

I started [Power Analysis Day](https://twitter.com/gojimmypi/status/1492178884883746820?s=20&t=vy_CMO37vpjmfwYx7sZaPw) with my backup board:
 


Here's a diagram of the full Power Analysis Setup:



See my [blog](https://gojimmypi.github.io/ppk2-power-analysis/) for additional Power Analysis setup information.

## What are the different states the device can be in?

That various sleep modes (and all the other HAL details) are discussed in the 2,600+ page [UM1884 PWR Firmware driver API description](https://www.st.com/resource/en/user_manual/dm00173145-description-of-stm32l4l4-hal-and-lowlayer-drivers-stmicroelectronics.pdf) guide. There are 8 main Power Modes and several sub-modes  summarized in [this STM32L4 Power Presentation](https://www.st.com/content/ccc/resource/training/technical/product_training/ce/57/a3/86/7a/3d/4d/87/STM32L4_System_Power.pdf/files/STM32L4_System_Power.pdf/jcr:conte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):



## How much will your device be in each state?

My goal is to have two main power modes: `On` and `Deep Sleep`. The `On` mode requires a whopping 120mA. I've not yet determined how to successfully put my device into sleep mode.

## How much current is used in each state?

I used a [Nordic Power Profile Kit](https://www.nordicsemi.com/Products/Development-hardware/Power-Profiler-Kit-2) to measure board power.

See [UM1884 Description of STM32L4/L4+ HAL and low-layer drivers](https://www.st.com/resource/en/user_manual/dm00173145-description-of-stm32l4l4-hal-and-lowlayer-drivers-stmicroelectronics.pdf) for information on `HAL_PWR_EnterSLEEPMode()`.

Curiously, even when paused in the debugger, there's a fluctuation in power:



These peripherals, many of which are unused for this project, also consume power (most are assumed in "off" low power state unless initialized, but they may need to be manualyl turned off).

* SPBTLE-RF Bluetooth

* SPSGRF-868 or SPSGRF-915 Sub-GHz (868 or 915 MHz) low-power-programmable RF module

* 64-Mbit Quad-SPI NOR Flash memory

* ISM43362-M3G-L44 Wi-Fi module Inventek system  (802.11 b/g/n compliant)

* MP34DT01 ST-MEMS microphones

* HTS221 relative humidity and temperature low-power consumption: 2 μA  (page 25).

* LPS22HB 260-1260 hPa absolute digital output barometer

* LIS3MDL High-performance 3-axis magnetometer

* VL53L0X Time-of-Flight and gesture detection sensor

* LED indicator lights (9x of them)

## How long will the device last given a 40mAh battery?

At 120mA draw, not very long. The dev board likely won't even power on!

This particular board was chosen for the Wi-Fi capabilities and many interesting peripherals built-in. Unless power is pulled to the BBQ Grill, there's an unreasonable amount of power needed
from basic batteries. Consideration will be given to forego the Wi-Fi capabilities, port the code to a [Blue Pill](https://hackaday.com/2021/01/20/blue-pill-vs-black-pill-transitioning-from-stm32f103-to-stm32f411/), 
and use a battery or perhaps solar power. At this point, the only feature implemented that will not be avilable is the baromatric sensor.

If using a Blue Pill, there's considerably lower power requirements:



Zooming out on the time scale, we see that the LED blinky has a noticable effect on the power profile:



Leaving the Green LED off, and unsoldering the red power LED, we can likely get the device current down to about 25mA during run mode.

This STM32 Blue Pill is using the [STM32F103C8T6](https://www.st.com/en/microcontrollers-microprocessors/stm32f103c8.html) "Mainstream Performance line, Arm Cortex-M3". 
The observed current is certainly in line with the [datasheet](https://www.st.com/resource/en/datasheet/stm32f103c8.pdf) specifications:



Relatively small sleep current:



Stop and standby current in the uA range:

 

If the display is only on for a total of a minute or so, with mostly stop current levels when the BBQ is not in use for sometimes weeks at a time, 
battery life will be quite reasonable.

If there's only 5uA of current in stop mode, a 40mA hour battey could keep the device alive for up to 8,000 hours, or nearly a year. Actual battery life and voltage retention
over time will vary depending on battery age, quality, and ambient temperature.

## Additional Information

### Caution

Do not connect the PC to the ST-LINK (CN7) when R30 is soldered. The PC may be damaged
or the board may not be powered correctly. From page 17 of [UM2153](https://www.st.com/resource/en/user_manual/um2153-discovery-kit-for-iot-node-multichannel-communication-with-stm32l4-stmicroelectronics.pdf)

### Power Tree

From page 18 of [UM2153](https://www.st.com/resource/en/user_manual/um2153-discovery-kit-for-iot-node-multichannel-communication-with-stm32l4-stmicroelectronics.pdf):



<< [Exercise 9](./Exercise_9.md) -- [Assignments](./README.md) --  END

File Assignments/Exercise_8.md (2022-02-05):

# Exercise 8 Heap and Stack Pointers

Compile your project code so it prints out the heap pointer and the stack pointer. Print out a global variable address. 
If you can find it, modify your linker file to swap your uninitialized variables and initialized variables. 
Verify it is as expected in the memory map. See how that changes your code output. 

Turn in your notes on what you found to Discord #assignment-submission by 9am on Jan 29th. 

Note: there will be more detailed hints on how to do this as the week goes on. If you get stuck, look in the Discord #homework-help for a Hints thread.

## Result

Here's the 
[stack](https://github.com/gojimmypi/IoT_BBQ/blob/106784c506af993e4949d96c450d91733ee2f3fe/IoT_BBQ_STM32/_main.c#L389), 
[heap](https://github.com/gojimmypi/IoT_BBQ/blob/106784c506af993e4949d96c450d91733ee2f3fe/IoT_BBQ_STM32/_main.c#L411), 
and [global variable](https://github.com/gojimmypi/IoT_BBQ/blob/106784c506af993e4949d96c450d91733ee2f3fe/IoT_BBQ_STM32/_main.c#L30) addresses printed out the UART:



Given two global variables, one [initialized](https://github.com/gojimmypi/IoT_BBQ/blob/d6a782fa75ff63185452af4ad6737e4db91b9b61/IoT_BBQ_STM32/_main.c#L32) with a value of `42`
and the other [not initialized](https://github.com/gojimmypi/IoT_BBQ/blob/d6a782fa75ff63185452af4ad6737e4db91b9b61/IoT_BBQ_STM32/_main.c#L31):

```
static int myNotInitializedVariable;
static int myInitializedVariable = 42;
```
The global addresses for each of the above variable are shown here, the messages sent out of the UART and received by `putty`:



Those addresses are confirmed by VisualGDB Global Live Watch:



Upon [swapping uninitialized variables and initialized variables](https://github.com/gojimmypi/IoT_BBQ/commit/176007658a9f9f787b2cf8d68e74c16a196d13ef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)
the new addresses were observed:



However the Global Live Watch result was unexpected:



Contrary to the Global Watch, the manual watch showed a value and address consistent with the `putty` output values: 

`0x20004440 <myInitializedVariable> {0x0000002a}`:



So which is correct? An [additional programmatic assignment](https://github.com/gojimmypi/IoT_BBQ/blob/688a7cbbd65cedb348adb1562dad32c2918f921b/IoT_BBQ_STM32/_main.c#L457) confirmed the value is indeed `42`: 

```
volatile int checkValue = myInitializedVariable;
```

## Stack Pointers

Variables in functions are stored on the stack. Thank you [stackoverflow for the reminder on how to determine the address of a variable on the stack](https://stackoverflow.com/questions/20059673/print-out-value-of-stack-pointer),
which of course is the most recent stack pointer:

```
        void* p = NULL;
        volatile long myStackPointer = (long)((void*)&p);
```

The address of the _next_ variable on the stack would be the current stack pointer plus the size of the latest object (or pointer) that was pushed onto the stack.

VisualGDB has the capability of showing live FreeRTOS environment details. Here the newly-allocated address of `p` has a value of `0x200013F0`:

stack_pointer_example

The live watch also helps us with the address of the stack pointer in this FreeRTOS thread: `0x20001418`. A means of determining this value directly from the inside of `[Raw TCB]` (shown above) has not yet been determined.

We can also observe that FreeRTOS apparently has (72-8 = 64) bytes of overhead on the stack, probably for the pre-emptive scheduler. 
Also shown is the stack starting in this thread at `pxTopOfStack = 0x200013c8`. 

The next value of the stack pointer was `0x200013c8` after [allocation](https://github.com/gojimmypi/IoT_BBQ/blob/106784c506af993e4949d96c450d91733ee2f3fe/IoT_BBQ_STM32/_main.c#L392)
of `int *q`. (`0x200013F0 - 0x200013e8 = 8`) byte change: the size of the `volatile long myStackPointer2`.

```
    void* p = NULL;
    volatile long myStackPointer = (long)((void*)&p);
    
    void* q = NULL;
    volatile long myStackPointer2 = (long)((void*)&q);

    int* r = (int*)0xAD;
    volatile long myStackPointer3 = (long)((void*)&r);
```

Unlike the stack, subsequent heap addresses may not be easily predictable, particularly when the heap becomes fragmented.

## Heap Size and Pointers

The heap size and pointers are a bit more interesting, particularly since the [Final Project](./Final_Project.md) is using and RTOS. The [FreeRTOS Memory Management](https://www.freertos.org/a00111.html) documentation was helpful here. 
In particular the [heap_4.c xPortGetFreeHeapSize()](https://github.com/STMicroelectronics/STM32CubeL4/blob/f93a2f74f8e9912405dbf1a297b6df0c423eddf2/Middlewares/Third_Party/FreeRTOS/Source/portable/MemMang/heap_4.c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) found in the 
[Github.com/STMicroelectronics/STM32CubeL4](https://github.com/STMicroelectronics/STM32CubeL4/) library. This code was also found to have been installed via STH32Cube here:

```
C:\Users\gojimmypi\STM32Cube\Repository\STM32Cube_FW_L4_V1.17.1\Middlewares\Third_Party\FreeRTOS\Source\portable\MemMang
```

Similar to the [Stack Pointers](https://github.com/gojimmypi/IoT_BBQ/blob/main/Assignments/Exercise_8.md#stack-pointers), the heap pointer is determined by allocating heap space via the RTOS `pvPortMalloc`, see 
[myHeapPointer](https://github.com/gojimmypi/IoT_BBQ/blob/106784c506af993e4949d96c450d91733ee2f3fe/IoT_BBQ_STM32/_main.c#L411):

```
myHeapPointer = (long)pvPortMalloc(1); // a non-zero param returns heap pointer
```

The VisualGDB FreeRTOS Live Watch verified the most recent allocation at address `0x20001ea0` as shown in the putty UART output [result](https://github.com/gojimmypi/IoT_BBQ/blob/main/Assignments/Exercise_8.md#result), above. 



## Linker File

The [linker file](./Exercise_8_STM32L475VG_flash.lds), `STM32L475VG_flash.lds` needed to be manually copied to the project directory, as by default it is located in:

```
C:\Users\gojimmypi\AppData\Local\VisualGDB\EmbeddedBSPs\arm-eabi\com.sysprogs.arm.stm32\STM32L4xxxx\LinkerScripts
```



Pressing the `Copy to project directory` did exactly that, changing the full path to just a file name located in the root of the project directory:



Delete the filename and leave it blank to have the default changed to the original path. The local project file is _not_ automatically deleted.

The [first line of the linker script](https://github.com/gojimmypi/IoT_BBQ/blob/main/Assignments/Exercise_8_STM32L475VG_flash.lds#L1) for VisualGDB indicates that it is generated by [this C# app](http://visualgdb.com/tools/LinkerScriptGenerator).
No local `LinkerScriptGenerator*.*`files were found.

The linker file is [configured to save the heap in SRAM](https://github.com/gojimmypi/IoT_BBQ/blob/90c0f3c8a2cc72bcf0247367f3cc2642e352d556/Assignments/Exercise_8_STM32L475VG_flash.lds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), 
as is the [stack](https://github.com/gojimmypi/IoT_BBQ/blob/90c0f3c8a2cc72bcf0247367f3cc2642e352d556/Assignments/Exercise_8_STM32L475VG_flash.lds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).

The [.bss](https://en.wikipedia.org/wiki/.bss) section _contains statically allocated variables that are declared but have not been assigned a value yet_. The 
[default](https://github.com/gojimmypi/IoT_BBQ/blob/0237a7ca264606b2d083d45d6de9c52a415f4bcd/Assignments/Exercise_8_STM32L475VG_flash.lds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) saves this data in SRAM.

TODO: where is uninitialized data defined in the linker file?

## Map file

The default setting was to _not_ generare a linker map file.

generate_map_file

Only a one instance of `.isr_vector` was found in the solution:

isr_vector_project_instances

Specifically, in this directory:

```
C:\Users\gojimmypi\AppData\Local\VisualGDB\EmbeddedBSPs\arm-eabi\com.sysprogs.arm.stm32\STM32L4xxxx\StartupFiles
```

But when seaching all files there were three instances

isr_vector_directory_instances

Specifically, `.isr_vector` was found in this directory at line [5,519](https://github.com/gojimmypi/IoT_BBQ/blob/4b319f3829f95a9f9d6610694b39b27357717030/Assignments/Exercise_8_IoT_BBQ_STM32.map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):

```
C:\workspace\IoT_BBQ\IoT_BBQ_STM32\VisualGDB\Debug
```

The [IoT_BBQ_STM32.map](./Exercise_8_IoT_BBQ_STM32.map) file is over 7,000 lines long. Additionally, when building the project, any manual changes are over-written by a fresh generation of the file.

## References:

* VisualGDB [Customizing Memory Layout of Embedded Programs with GNU Linker Scripts](https://visualgdb.com/tutorials/arm/linkerscripts/)
* FreeRTOS [Memory allocation implementations included in the RTOS source code download](https://www.freertos.org/a00111.html)
* Stackoverflow [Print out value of stack pointer](https://stackoverflow.com/questions/20059673/print-out-value-of-stack-pointer)
* ST Community [How to check stack and heap usage during run time.](https://community.st.com/s/question/0D50X00009XkWiq/how-to-check-stack-and-heap-usage-during-run-time)
* ST [Description of STM32L4/L4+ HAL and low-layer drivers - UM1884](https://www.st.com/resource/en/user_manual/dm00173145-description-of-stm32l4l4-hal-and-lowlayer-drivers-stmicroelectronics.pdf)

<< [Exercise 7](./Exercise_7.md) -- [Assignments](./README.md) --  [Exercise 9](./Exercise_9.md) >>

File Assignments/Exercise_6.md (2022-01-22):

# Exercise 6 Review the final project instructions. 

From [classpert file](https://cdn.classpert.com/uploads/36e0ddd5d53853a98b3792ca8a348ff0-419439.pdf):

## Put together a preliminary rough draft of your final report.

See the WIP [Final Project Document](./Final_Project.md) and the [Supplementary Instructions](./Final_Project_Instructions.md).

> This is intended to be a planning exercise, not that you should have your project complete
(though it makes the report easier to write if you put it in present/past tense instead of putting in
“should” and “shall”).

## As you work through the draft final report, note where you might have trouble. 

The [Final Project Challenges](./Final_Project.md#Challenges) lists tasks that may be difficult to address.

## Make a list of the tasks you want to complete for the project. 

The [Minimum Project Requirements](./Final_Project.md#Challenges#minimum-project-requirements) should certainly be completed:

[(a) Use a Cortex-M processor](./Final_Project.md#a-use-a-cortex-m-processor)

[(b) Have a button that causes an interrupt](./Final_Project.md#b-have-a-button-that-causes-an-interrupt)

[(c) Use at least three peripherals such as ADC, DAC, PWM LED, Smart LED, LCD, sensor, BLE](./Final_Project.md#c-use-at-least-three-peripherals-such-as-adc-dac-pwm-led-smart-led-lcd-sensor-ble)

[(d) Have serial port output](./Final_Project.md#d-have-serial-port-output)

[(e) Implement an algorithmic piece that makes the system interesting](./Final_Project.md#e-implement-an-algorithmic-piece-that-makes-the-system-interesting)

[(f) Implement a state machine](./Final_Project.md#f-implement-a-state-machine)

Beyond the requirements for the class, ideas to consider:

* Firebox temperature
* Solar power
* LoRa communication
* Internet conenctivity: web page to view weight, some sort of MQTT publish/subscribe/history.
* Design a PCB with minimum components and all hardware used properly embedded with no prototype mechanical dupont conenctors.

## Make a list of the minimum viable project and any blocking items (unacquired hardware, difficulty with toolchains).

The minimum viable project will be a system that:

* Read the weight and convert to digital value.
* Display the weight.

## Include any relevant pieces from past assignments (such as the state machine documentation from Exercise 5).

* The [Exercise 2 Idea Project Diagram](./Exercise_2_1.md#idea-project-diagram) is a helpful overview.
* [Exercise 4 Buttons Registers](./Exercise_4.md#what-are-the-button-registers-that-you-read)

Turn in your document or a link to a github document before 9am on Saturday, January 15.

<< [Exercise 5](./Exercise_5.md) -- [Assignments](./README.md) --  [Exercise 7](./Exercise_7.md) >>

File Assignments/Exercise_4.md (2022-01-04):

# Exercise 4: Make Blinky

From [Exercise Details](https://docs.google.com/document/d/1WRuzWj_VNoX0qyKoqVu3rr-ARXuEJDw9B2tnH1ZX_uE/edit):

On your final project board, make blinky for yourself. Then add a button to turn the LED on and off. 
Bonus points for making the button cause an interrupt. Triple bonus points for debouncing the button signal.

## What are the hardware registers that cause the LED to turn on and off? (From the processor manual, don’t worry about initialization.) 

My [Initial VisualGDB project](https://github.com/gojimmypi/IoT_BBQ/tree/f9dab949fbbb88e6c5072c864743b30965233673/IoT_BBQ_STM32) 
coincidentally happened to be a [Blinky for RTOS](https://github.com/gojimmypi/IoT_BBQ/blob/f9dab949fbbb88e6c5072c864743b30965233673/IoT_BBQ_STM32/IoT_BBQ_STM32.c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).

Unfortunately, the [default GPIO assignments for that tempate project](https://github.com/gojimmypi/IoT_BBQ/blob/f9dab949fbbb88e6c5072c864743b30965233673/IoT_BBQ_STM32/IoT_BBQ_STM32.c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)
were incorrect. Instead of [GPIO_PIN_12 and GPIO_PIN_13](https://github.com/gojimmypi/IoT_BBQ/commit/67924b3a7dde185c6e0f1158f6e9990a50225455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)
I found that my board has LEDs `LED1` on Port A [GPIO_PIN_5](https://github.com/gojimmypi/IoT_BBQ/blob/67924b3a7dde185c6e0f1158f6e9990a50225455/IoT_BBQ_STM32/IoT_BBQ_STM32.c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)
and `LED2` on Port B [GPIO_PIN_14](https://github.com/gojimmypi/IoT_BBQ/blob/67924b3a7dde185c6e0f1158f6e9990a50225455/IoT_BBQ_STM32/IoT_BBQ_STM32.c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) as shown in Table 2 in Chapter 7 of the 
[User Manual](https://www.st.com/resource/en/user_manual/um2153-discovery-kit-for-iot-node-multichannel-communication-with-stm32l4-stmicroelectronics.pdf):



## What are the button registers that you read? 

There are 2 buttons on my board: `B1`, _RESET_ and `B2` _Wake-Up_. Although not specified in the table above, there's indication on the schematic (page 43) of the 
[User Manual](https://www.st.com/resource/en/user_manual/um2153-discovery-kit-for-iot-node-multichannel-communication-with-stm32l4-stmicroelectronics.pdf) that the Wake-up button is
found on Pin 7, Port C GPIO13:



See also the `B2` detail on page 51, noting in particular there's already a 100K pullup resistor, `R23`:



Additionally, note there's already a built-in RC debounce at `C36`, `C37` and `R24`.

## Can you read that memory directly and see the button change in a debugger or by printing out the associated memory?

There's a HAL function called [HAL_GPIO_ReadPin](https://github.com/gojimmypi/IoT_BBQ/blob/18babdb9736c54fd5a585352d3bb2d1d7c56bac0/IoT_BBQ_STM32/_main.c#L152) 
that by default when the switch is _not_ pressed, returns a value of `GPIO_PIN_SET` ("on", which is expected, given the pullup resistor, and normally-open switch)



When single step debugging, and the button is then pressed, the [next call to HAL_GPIO_ReadPin](https://github.com/gojimmypi/IoT_BBQ/blob/18babdb9736c54fd5a585352d3bb2d1d7c56bac0/IoT_BBQ_STM32/_main.c#L156) returns a value of `GPIO_PIN_RESET`  ("off", which when pressed, pulls the line to ground)



The code for this HAL function is found in `stm32l4xx_hal_gpio.c` and looks like this:



One _could_ read directly from `(GPIOx->IDR & GPIO_Pin)`, although for code portability it is best to use the HAL.

## Turn in your code with a comment or additional file answering the questions.

See [project files](https://github.com/gojimmypi/IoT_BBQ/tree/a850251c842d0874489bd994279bdcde903882a5), in particular, [main()](https://github.com/gojimmypi/IoT_BBQ/blob/a850251c842d0874489bd994279bdcde903882a5/IoT_BBQ_STM32/_main.c#L95).
There are 2 separate RTOS threads for controlling [LED1](https://github.com/gojimmypi/IoT_BBQ/blob/a850251c842d0874489bd994279bdcde903882a5/IoT_BBQ_STM32/_main.c#L210)
and [LED2](https://github.com/gojimmypi/IoT_BBQ/blob/a850251c842d0874489bd994279bdcde903882a5/IoT_BBQ_STM32/_main.c#L213).

The final version of my blinky uses the push button to control the [mode](https://github.com/gojimmypi/IoT_BBQ/blob/85dd40f15f56ba21bfe317fba5d7d07867083e23/IoT_BBQ_STM32/_main.c#L46) of the `LD2` LED: 

 - `IsBlinking` alternates between [LED_ON()](https://github.com/gojimmypi/IoT_BBQ/blob/85dd40f15f56ba21bfe317fba5d7d07867083e23/IoT_BBQ_STM32/_main.c#L243) and [LED_OFF()](https://github.com/gojimmypi/IoT_BBQ/blob/85dd40f15f56ba21bfe317fba5d7d07867083e23/IoT_BBQ_STM32/_main.c#L269)
 - `AlwaysOn`  even if the `LED_OFF()` is called, this mode ensure the `LD2` LED is [always on](https://github.com/gojimmypi/IoT_BBQ/blob/85dd40f15f56ba21bfe317fba5d7d07867083e23/IoT_BBQ_STM32/_main.c#L273).
 - `AlwaysOff` even if the `LED_ON()` is called, this mode ensure the `LD2` LED is [always off](https://github.com/gojimmypi/IoT_BBQ/blob/85dd40f15f56ba21bfe317fba5d7d07867083e23/IoT_BBQ_STM32/_main.c#L251).

 As there are 2 LEDs the target blinky `LD2`, and the other, `LD1` is used to indicate blinky mode:
 - `IsBlinking` - `LD1` blinks once, then pauses. repeat; `LD2` is blinking on 555ms duration on, and 555ms off.
 - `AlwaysOn` - `LD1` blinks twice, then pauses. repeat; `LD2` stays on.
 - `AlwaysOff` - `LD1` blinks three times, then pauses. repeat; `LD2` stays off.

Here's a YouTube video of the blinky in action: 
RTOS Blinky YouTube (https://www.youtube.com/watch?v=RCKf-NEh-AY)

## Discussion Points:

### Why does the author use “marketing comes to you” through this chapter? How does it relate to previous chapters?
Pretty much every programmer knows that the requirements continually evolve and change for just about every project. Embedded development is no different. 
Often times, it is the marketing folks that have "insight" and new ideas of what consumers want.

### Would you rather use a HAL or not? Why? What are the advantages either way?
I would prefer to use a HAL unless there were memory contraints.
The HAL will typically be larger code size, but more easily portable between different target processors.

### Peer review button blinkies
(to be done in class)

### Given an input interrupt, output(s), and timers, what could you build? How many things are just a combination of these?
Limited by the imagingation! An output could trigger anything from a simple LED to a massive solid state relay controlling high-current / high voltage systems.

## Initialization:

The LED initialization looks like this:

```
    __GPIOA_CLK_ENABLE();
    __GPIOB_CLK_ENABLE();

	GPIO_InitTypeDef GPIO_InitStructureA;

    GPIO_InitStructureA.Pin = GPIO_PIN_5;

    GPIO_InitStructureA.Mode = GPIO_MODE_OUTPUT_PP;
    GPIO_InitStructureA.Speed = GPIO_SPEED_FREQ_HIGH;
    GPIO_InitStructureA.Pull = GPIO_NOPULL;
    HAL_GPIO_Init(GPIOA, &GPIO_InitStructureA);

    GPIO_InitTypeDef GPIO_InitStructureB;

    GPIO_InitStructureB.Pin = GPIO_PIN_14;

    GPIO_InitStructureB.Mode = GPIO_MODE_OUTPUT_PP;
    GPIO_InitStructureB.Speed = GPIO_SPEED_FREQ_HIGH;
    GPIO_InitStructureB.Pull = GPIO_NOPULL;
    HAL_GPIO_Init(GPIOB, &GPIO_InitStructureB);

```

The Button initialization looks like this:

```
    // Initialize Port C
    GPIO_InitTypeDef GPIO_InitStructureC;

    GPIO_InitStructureC.Pin = GPIO_PIN_13;

    GPIO_InitStructureC.Mode = GPIO_MODE_INPUT;
    GPIO_InitStructureC.Speed = GPIO_SPEED_FREQ_HIGH;
    GPIO_InitStructureC.Pull = GPIO_NOPULL;
    HAL_GPIO_Init(GPIOC, &GPIO_InitStructureC);
    
    // create a SwitchState variable to hold the result of out button press 
    GPIO_PinState SwitchState;
```

<< [Exercise 3b](./Exercise_3b.md) -- [Assignments](./README.md) -- [Exercise 5](./Exercise_5.md) >>

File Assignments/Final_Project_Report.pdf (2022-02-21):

Final_Project_Report.md | 2/20/2022

# Final Project Report

This Final Project Report is a supplement to the Final Project Minimum Project Requirement Detail. An embedded microscontroller was used to create a propane tank weight measurement system. Source code (https://github.com/gojimmypi/IoT_BBQ/tree/main/IoT_BBQ_STM32) is available on GitHub.

See also the YouTube Video: (https://youtu.be/YIoqKTbCUQQ)


## Application Description

This application is an embedded controller to monitor grill propane tank weight to replace the existing mechanical spring scale:


## Hardware Description

This project uses the STM32L475VG, (https://www.st.com/resource/en/datasheet/stm32l475vg.pdf) part of the STM32 Ultra Low Power (https://www.st.com/en/microcontrollers-microprocessors/stm32-ultra-low-power-mcus.html) Arm Cortex-M4 32-bit MCU+FPU series found on the B-L475E-IOT01A Discovery Board. (https://www.st.com/resource/en/user_manual/um2153-discovery-kit-for-iot-node-multichannel-communication-with-stm32l4-stmicroelectronics.pdf)

## Software description

The application is written in C/C++ and targets the STM32 ARM Platform.

Describe the code in general

The code is a multi-threaded FreeRTOS embedded application. There are 5 threads names LED1, LED2, UART1, DISPLAY, and PWM.

LED1 Thread

The LED1 Thread (https://github.com/gojimmypi/IoT_BBQ/blob/main/IoT_BBQ_STM32/_main_LED_Thread1.c) is a simple state machine and controls LED1 (blinky, on, or off). This thread also sends pressure reading and scale weight text to the UART.

LED2 Thread

The LED1 Thread (https://github.com/gojimmypi/IoT_BBQ/blob/main/IoT_BBQ_STM32/_main_LED_Thread2.c) monitors the state machine and blinks LED2 depending on the current state:

IsBlinking - one blink
AlwaysOn - two blinks
AlwaysOff - three blinks

UART1 Thread

Just to test RTOS concurrency (and hard fault avoidance!) the UART1 Thread sends a "Hello UART1" message to the UART about every 1.35 seconds. An odd number was chosen to ensure pseudo-random conflicts in timing with other messages.


This particular screen snip (above) is interesting. Note the seemingly stray "105" value. Apparetly this where the thread tried to grab a mutex to use the UART, but it was not available on a timely basis, so it skipped thhe entire "1 weight" part of the message. Recall this occurs in two steps: (https://github.com/gojimmypi/IoT_BBQ/blob/29255d7aa78ec70aa6fd3b76e06db336202eda09/IoT_BBQ_STM32/_main_LED_Thread1.c)

UART_TxMessageIntValue(WeightMessage, sizeof(WeightMessage), CurrentTankWeight);; UART_TxMessage(CrLf, sizeof(CrLf));

// (RTOS Thread swtich occured around here)

DISPLAY Thread

The Display Thread (https://github.com/gojimmypi/IoT_BBQ/blob/main/IoT_BBQ_STM32/DISPLAY/DISPLAY.cpp) is where the scale is monitored and the value dispalyed on the screen. There's also a small state machine monitoring for a button long press to then tare the scale and save the offset value to flash.

PWM Thread

The PWM thread (https://github.com/gojimmypi/IoT_BBQ/blob/main/IoT_BBQ_STM32/_main_pwm_thread.c) is included only for "interesting" experiements and is not required for basic functionality.

After some initial code experiments, the thread runs in a loop sending barometric pressure reading to the UART every 2 seconds.

Code Explorer View of main() (https://github.com/gojimmypi/IoT_BBQ/blob/main/IoT_BBQ_STM32/_main.c)



Describe the parts you wrote in some detail (maybe 3-5 sentences per module)

The main code repository can be found at github.com/gojimmypi/IoT_BBQ/tree/main/IoT_BBQ_STM32. MIT License.

Display Code (https://github.com/gojimmypi/IoT_BBQ/tree/main/IoT_BBQ_STM32/DISPLAY) was written specifically for this project. MIT License.

Flash Config (https://github.com/gojimmypi/IoT_BBQ/blob/main/IoT_BBQ_STM32/Flash/flash_config.h) was created from scratch for this project. MIT license.

LED Blinky and State Machine (https://github.com/gojimmypi/IoT_BBQ/tree/main/IoT_BBQ_STM32/LED) created by gojimmypi for this project. MIT license.

UART (https://github.com/gojimmypi/IoT_BBQ/tree/main/IoT_BBQ_STM32/UART) created for this project, MIT license. Uses stm32l4xx_hal.h (https://github.com/STMicroelectronics/STM32CubeL4/blob/master/Drivers/STM32L4xx_HAL_Driver/Inc/stm32l4xx_hal.h) assumed to still be BSD 3-Clause license (https://github.com/STMicroelectronics/STM32CubeL4/blob/d023c0d560ace11509f9b761c8913a9e48fcf194/Drivers/STM32L4xx_HAL_Driver/Src/stm32l4xx_hal.c)

Describe code you re-used from other sources, including the licenses for those

This project was created using the Sysprogs VisualGDB Extension (https://visualgdb.com/?features=embedded) for Visual Studio 2019. (https://docs.microsoft.com/en-us/visualstudio/releases/2019/release-notes) A tiny amount of initialization code was generated using the STM32CubeIDE. (https://www.st.com/en/development-tools/stm32cubeide.html)

HX711 Arduino Library (https://github.com/bogde/HX711) was ported to this STM32 HAL environment with FreeRTOS support. MIT License.

STM hsensor HAL (https://github.com/STMicroelectronics/STM32CubeL4/blob/master/Drivers/BSP/B-L475E-IOT01/stm32l475e_iot01_hsensor.c) BSD 3-Clause license.

STM Pressure Sensor HAL (https://github.com/STMicroelectronics/STM32CubeL4/blob/master/Drivers/BSP/B-L475E-IOT01/stm32l475e_iot01_psensor.h) BSD 3-Clause license

ssd1306 display driver (https://github.com/afiskon/stm32-ssd1306) was created by Aleksander Alekseev and modified (https://github.com/gojimmypi/IoT_BBQ/commits/main/IoT_BBQ_STM32/SSD1306) for this project. MIT License

Flash HAL (https://github.com/STMicroelectronics/STM32CubeL4/blob/master/Drivers/STM32L4xx_HAL_Driver/Src/stm32l4xx_hal_flash.c). Assumed to still be Licensed by ST under BSD 3-Clause license, but the license File is now blank. (https://github.com/STMicroelectronics/STM32CubeL4/issues/63)

Additional thanks to Elecia White (the Making Embedded Systems Instructor) for the code review, in particular to help find the cause of those nasty Hard Faults. Also thanks to the class mentors Erin, Daniel, Thomas, and Jeff... as well as all my classmates on the discord channel. A lot of smart and creative people with all sorts of interesting ideas!

## Diagram(s) of the architecture

Show below is the basic diagram of the architecture. The network feature has not yet been implemented:


## Build Instructions

There are two options for building: the GUI from Visual Studio and a command-line batch file, both on Windows.

Build in Visual Studio

Open the Visual Studio Solution File called IoT_BBQ_STM32.sln. (https://github.com/gojimmypi/IoT_BBQ/blob/main/IoT_BBQ_STM32/IoT_BBQ_STM32.sln) Find the IoT_BBQ_STM32 Project. Right-click and select "Build...":


To build and upload code, simply click the green VisualGDB Debugger button:

If the build was successful, the code will be sent to the board:


Build from Command-Line

If the STM32 toolchain is installed (for Windows) there's also an auto-generated batch file (https://github.com/gojimmypi/IoT_BBQ/blob/main/IoT_BBQ_STM32/IoT_BBQ_STM32-Debug.bat) to build from

command-line.

See also Project Readme Build Instructions (https://github.com/gojimmypi/IoT_BBQ/tree/main/IoT_BBQ_STM32#build-from-a-batch-file)

How to build the system (including the toolchain(s))

The only toolchain required for this project is the VisualGDB Extension (https://visualgdb.com/). See the Developing STM32 projects with Visual Studio walk-through. (https://visualgdb.com/tutorials/arm/stm32/)

These settings are included the project solution file but included here for reference:

Project Config Step 1:


Project Config Step 2:


Project Config Step 3:


See above for the build instructions. (https://github.com/gojimmypi/IoT_BBQ/blob/main/Assignments/Final_Project_Report.md)

Hardware

Mouser ST B-L475E-IOT01A1 (https://www.mouser.com/ProductDetail/stmicroelectronics/b-l475e-iot01a1/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)
Amazon SSD1306 I2C Serial (https://www.amazon.com/dp/B08KY21SR2/)
Sparkfun Load Cell Amplifier HX711 (https://www.sparkfun.com/products/13879?_ga=2.84341273.1032917369.1645317851-1685161029.1637878826)
Adafruit Strain Gauge Load Cell - 4 Wires - 20Kg (https://www.adafruit.com/product/4543)

Hardware wiring diagram:


Software

The source code can be downloaded from GitHub gojimmypi/IoT_BBQ. (https://github.com/gojimmypi/IoT_BBQ) The only other software needed is Visual Studio and VisualGDB (and an internet connection, as VissualGDB will download and install toolchains and libraries as needed.)

How you debugged and tested the system

All of the development and debugging was completed in Visual Studio using breakpoints and the single-step-debugging features available from the VisualGDB extension.

Single-step inspection:


Heap pointer check:


Memory address inspection:


Breakpoints, code explorer, and other system monitoring features were quite helpful:

## Future

Although the discovery board was convenient from a getting started perspective, it is also massive and power hungry. The next steps are to port this project to a Blue Pill.

## What would be needed to get this project ready for production?

Key to a production deployment would be an enclosure and some way to have them mass-produced. For large-scale production, some means of mass-programming the devices would be needed. It would not be practical to manually plug in a million boards and program them each one at a time.

## How would you extend this project to do something more? Are there other features youd like? How would you go about adding them?

I chose the this particular IoT Discovery board for the WiFi capabilities. As it turns out, the power consumption is simply way too high for battery operation. Our grill is located a bit far from the house; I certainly don't want to run an extension cord. I have some LoRa experience (https://gojimmypi.github.io/tag/lora/) and plan to see if I can get that working with an MQTT server.

There are also plans for including a firebox temperature sensor, specifically the MAX6675 Module + K Type Thermocouple Temperature as described in the original README (https://github.com/gojimmypi/IoT_BBQ/blob/main/README.md#iot_bbq) from a few years back when I created something for the ESP8266.

## Grading

Self assessment of the project: for each criteria, choose a score (1, 2, 3) and explain your reason for the score in 1-2 sentences. Have you gone beyond the base requirements? How so?

Criteria

1 - Needs
Improvement

2 - Meets Expectations 3 - Exceeds Expectations

Project meets
minimum project
goals

2+ Basic State Machine, (https://github.com/gojimmypi/IoT_BBQ/blob/cc7372a3d11caf1aeab8de3807fefd8d7b27aa1b/IoT_BBQ_STM32/LED/LED.cpp)
additional sensors
LPS22HB, (https://github.com/gojimmypi/IoT_BBQ/tree/main/IoT_BBQ_STM32/LPS22HB) HX711, (https://github.com/gojimmypi/IoT_BBQ/tree/main/IoT_BBQ_STM32/HX711) well
documented. No serial
commands

Completeness of
deliverables

Readable code, each point addressed, (https://github.com/gojimmypi/IoT_BBQ/blob/main/Assignments/Final_Project.md) video (https://youtu.be/YIoqKTbCUQQ)

Clear intentions
and working
code

2+ System works as
decribed

(docs not as professionally polished as I'd like)

Reusing code | License summary (https://github.com/gojimmypi/IoT_BBQ/blob/main/Assignments/Final_Project_Report.md) and Build Info (https://github.com/gojimmypi/IoT_BBQ/blob/main/Assignments/Final_Project_Report.md)

Originality and
scope of goals

This is clearly an awesome Propane Tank Weight Project! The scope of goals was appropriately challenging yet reasonable for the class.

Criteria; 1 - Needs Improvement; 2 - Meets Expectations; 3 - Exceeds Expectations; Self-assessment (Mentor category only); Bonus: Power analysis, firmware update, or system profiling; Power Analysis also shared on Twitter; ! Bonus: Version control was used.; hundreds of commits

I created the video footage of the project in action on my phone and took all the pictures, but the final consolidated video was assembled and subtitled by someone else. Thank you!!!

See the Class Assignment additional links (https://github.com/gojimmypi/IoT_BBQ/tree/main/Assignments#links) for other resources.

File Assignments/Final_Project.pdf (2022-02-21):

Final_Project.md | 2/20/2022

# Final Project

This document addresses the Final Project Instructions for the Making Embedded Systems (https://lms.classpert.com/classpert-x/courses/making-embedded-systems-wUXIUA) class.

The objective is to create Propane Tank Weight Sensor System with something considerably more accurate and precise to replace the stock mechanical spring gauge:


## Minimum Project Requirements

The project must:
(a) Use a Cortex-M processor:

This project is using an STMicro STML4, specifically the STM32L475VG, (https://www.st.com/resource/en/datasheet/stm32l475vg.pdf) part of the STM32 Ultra Low Power (https://www.st.com/en/microcontrollers-microprocessors/stm32-ultra-low-power-mcus.html) Arm Cortex-M4 32-bit MCU+FPU series found on the B-L475E-IOT01A Discovery Board. (https://www.st.com/resource/en/user_manual/um2153-discovery-kit-for-iot-node-multichannel-communication-with-stm32l4-stmicroelectronics.pdf)

The prototype uses the Discovery kit for IoT node. (https://www.st.com/resource/en/user_manual/um2153-discovery-kit-for-iot-node-multichannel-communication-with-stm32l4-stmicroelectronics.pdf)

(b) Have a button that causes an interrupt

This project leverages the code from Exercise 4 that implements an operational mode/state switch via interrupt-driven button press code. There's a small button library as well as the interrupt handler that deals with button presses and system state changes.
(c) Use at least three peripherals such as ADC, DAC, PWM LED, Smart LED, LCD, sensor, BLE

The peripherals used in the project:

External:

Load cell (weight sensor) such as the SparkFun HX711. (https://www.sparkfun.com/products/13879) See HX711 code.

Display: SSD1306 OLED Dual Color (Yellow / Blue) such as this I2C Serial 12864 on Amazon (https://www.amazon.com/dp/B08KY21SR2/) that includes mbedded Driver IC. See SSD1306 code

Temperature Sensor (The onboard device TODO specify)

Internal

Onboard LED: See LED code


The built-in STM32L475 Flash is used to save tare weight offset. (see code). There's a check for button long press in the RTOS Display Thread, here. Upon detecting a button long press, the display thread is paused and a new system Tare state is assigned. Upon entering the Tare State (https://github.com/gojimmypi/IoT_BBQ/blob/c9316d246b56a14a15f69095f7e19a288091ab0c/IoT_BBQ_STM32/DISPLAY/DISPLAY.cpp) the the display is cleared, the message "Tare" is displayed, and the calculated offset (https://github.com/gojimmypi/IoT_BBQ/blob/c9316d246b56a14a15f69095f7e19a288091ab0c/IoT_BBQ_STM32/HX711/HX711.cpp) is saved to flash via SaveDeviceConfig() from the DoScaleTare() task. (https://github.com/gojimmypi/IoT_BBQ/blob/c9316d246b56a14a15f69095f7e19a288091ab0c/IoT_BBQ_STM32/Flash/flash_config.c)

See the customized linker file (https://github.com/gojimmypi/IoT_BBQ/blob/16c2e625e0a9bc0637c29e78947d009f5d849b26/IoT_BBQ_STM32/STM32L475VG_flash.lds) that placed Flash memory starting at FDATA = 0x080FF000

MEMORY {

FLASH (RX) : ORIGIN = 0x08000000, LENGTH = 996K FDATA (R) : ORIGIN = 0x080FF000, LENGTH = 4K SRAM (RWX) : ORIGIN = 0x20000000, LENGTH = 96K RAM2 (RWX) : ORIGIN = 0x10000000, LENGTH = 32K

The Flash configuration is mapped to the static const struct FlashConfig FLASH_CONFIG (https://github.com/gojimmypi/IoT_BBQ/blob/16c2e625e0a9bc0637c29e78947d009f5d849b26/IoT_BBQ_STM32/Flash/flash_config.c) in Flash memory, along with a copy in an updatable RAM cache value:

__attribute__((__section__(".flash_user_data"))) static const struct FlashConfig FLASH_CONFIG;; DeviceCacheConfig() static struct FlashConfig CACHE_CONFIG;

// FLASH_CONFIG is the data actually on the flash. See DeviceFlashConfig()

// CACHE_CONFIG is the runtime, updatable copy of the config. See

The on-board LPS22HB barometric sensor (https://www.st.com/en/mems-and-sensors/lps22hb.html) was used in this project (see code). Currently the pressure reading is sent to the UART in the RTOS LED Thread #11. To make things interesting from a multi-threadced RTOS perspective, the pressure is also read in the experimental PWM Thread.

PWM Timers and watchdogs

There are some experiments with STM32 PWM in the PWM Thread, but this was done only for educational purposes and will be removed from the final project.

See Page 44 of the STM32L475xx Datasheet (DS10969): (https://www.st.com/resource/en/datasheet/stm32l475vg.pdf)


(d) Have serial port output

See UART code. Several of the RTOS threads send data to the UART, including the main LED Thread1 (https://github.com/gojimmypi/IoT_BBQ/blob/200882b131afad40577f094373feec7bd9153e3a/IoT_BBQ_STM32/_main_LED_Thread1.c) and the experimental PWN Thread. (https://github.com/gojimmypi/IoT_BBQ/blob/200882b131afad40577f094373feec7bd9153e3a/IoT_BBQ_STM32/_main_pwm_thread.c)

An RTOS-safe semaphore wrapper (https://github.com/gojimmypi/IoT_BBQ/blob/200882b131afad40577f094373feec7bd9153e3a/IoT_BBQ_STM32/UART/UART.cpp) was created around the HAL_UART_Transmit found in the STMicroelectronics / stm32l4xx_hal_driver / stm32l4xx_hal_uart.c. (https://github.com/STMicroelectronics/stm32l4xx_hal_driver/blob/master/Src/stm32l4xx_hal_uart.c)

Sample UART output at startup:


(e) Implement an algorithmic piece that makes the system interesting

Every sensor is a temperature sensor. Some are better than others. --Unknown / Elecia White (https://electronics.stackexchange.com/questions/386691/who-said-all-sensors-are-temperature-sensors-but-some-are-better-than-others)

Consider measuring weight over time and temperature.

TODO: interesting
(f) Implement a state machine

There's currently a prototype LED State Machine (https://github.com/gojimmypi/IoT_BBQ/blob/ce44c00152af0a16b26d9a246a799ed7db8553ae/IoT_BBQ_STM32/LED/LED.cpp) with IsBlinking, AlwaysOn, AlwaysOff (https://github.com/gojimmypi/IoT_BBQ/blob/ce44c00152af0a16b26d9a246a799ed7db8553ae/IoT_BBQ_STM32/LED/LED.h) states.
Not required to use a HAL (but it is encouraged)

This project uses the STM32L4XX HAL, (https://github.com/STMicroelectronics/stm32l4xx_hal_driver) for example here, (https://github.com/gojimmypi/IoT_BBQ/blob/ce44c00152af0a16b26d9a246a799ed7db8553ae/IoT_BBQ_STM32/_main.c) and is a multi-threaded application using embedded RTOS (specfically CMSIS_RTOS) (https://arm-software.github.io/CMSIS_5/RTOS2/html/rtos_api2.html) for example included here. (https://github.com/gojimmypi/IoT_BBQ/blob/ce44c00152af0a16b26d9a246a799ed7db8553ae/IoT_BBQ_STM32/_main.c)

Code that uses the STM32 HAL will need the #include <stm32l4xx_hal.h>. Future versions of this codebase should include a hardware conditional include such as this (https://github.com/gojimmypi/IoT_BBQ/blob/314d03bb8053d09c3730533c384fd499d35e3231/IoT_BBQ_STM32/SSD1306/ssd1306.h) example:

#if defined(STM32F0)

#include "stm32f0xx_hal.h"

#elif defined(STM32F1)

#include "stm32f1xx_hal.h" #elif defined(STM32F4)

#include "stm32f4xx_hal.h" #include "stm32f4xx_hal_gpio.h" #elif defined(STM32L0)

#include "stm32l0xx_hal.h" #elif defined(STM32L1)

#include "stm32l1xx_hal.h" #elif defined(STM32L4)

#include "stm32l4xx_hal.h" #elif defined(STM32F3)

#include "stm32f3xx_hal.h" #elif defined(STM32H7)

#include "stm32h7xx_hal.h" #elif defined(STM32F7)

#include "stm32f7xx_hal.h" #elif defined(STM32G0)

#include "stm32g0xx_hal.h" #elif defined(STM32G4)

#include "stm32g4xx_hal.h"

#else

#error "Hardware platform not supported." #endif

## List of the tasks to complete for the project

Confirm operational display
Confirm operational weight sensor
Show weight value on display
Update docs on new I2C port being used for SSD1306 Confirm serial port operation
Implement Serial Rx/Tx
Implement serial debug messages
Sleep serial port when inactive Implement Sleep / Wake-up
Determine field power source Design enclosure
Print enclosure
Mount hardware in enclosure
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

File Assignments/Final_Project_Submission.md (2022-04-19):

# Making Embedded Systems Project Submission.

Propane Tank Weight Measurement System

## (a) Video of the system working as intended.

[YouTube Video](https://youtu.be/YIoqKTbCUQQ):

(https://youtu.be/YIoqKTbCUQQ)

## (b) Write up of the system (PDF or Google docs report). 

[Final Project Report](./Final_Project_Report.md) also as ([PDF](./Final_Project_Report.pdf)) (addresses the [Report Section of Final Project Instructions](https://github.com/gojimmypi/IoT_BBQ/blob/main/Assignments/Final_Project_Instructions.md#report))

[Final Project](./Final_Project.md) also as ([PDF](./Final_Project.pdf)) (addresses the [Final Project Instructions](./Final_Project_Instructions.md))

## (c) Link to the code: 

Source code can be found at [GitHub IoT BBQ STM32 Project](https://github.com/gojimmypi/IoT_BBQ/tree/main/IoT_BBQ_STM32).

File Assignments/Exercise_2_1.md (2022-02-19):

# Idea project diagram.

Exercise 2.1 for [Making Embedded Systems](https://lms.classpert.com/classpertx/courses/making-embedded-systems/cohort) class. See [Assignment Index](./README.md)

● Make a block diagram describing an embedded system you’d like to have or make. Be
imaginative. Reality does not apply here.



<< [Exercise 1](./Exercise_1.md) -- [Assignments](./README.md) -- [Exercise 2.2](./Exercise_2_2.md) >>

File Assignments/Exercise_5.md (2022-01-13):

# Exercise 5: State Machine Documentation

- 1 Start putting together a plan for your final project. Given the chapter, the main goal is to
put together state machine documentation. This can be a flowchart or (preferably) a
state table. You may also need to create the diagrams from Lesson 2 to flesh out the
design. Note: this design planning, thinking through the system, what you have and
what you need. Keep in mind that these will not be the final version!

**State**   | **Action** | **Display** | **Sensor** | **Off** | **Mode**    | **Button** | **Timeout**
:----------:|:----------:|:-----------:|:----------:|:-------:|:-----------:|:----------:|:-----------:
Start       |        init|  Hello      |READ\_WEIGHT|         |             |            | 
CHOOSE\_MODE| Show Mode  |   read      |READ\_WEIGHT|         |             |            | 
GOODBYE     | Save       |        BYE  |            |         |             |            | 
RUN         |  Get Weight|  Show Weight|READ\_WEIGHT| GOODBYE | CHOOSE\_MODE|            | RUN
TARE        | init sensor| Show Tare   |READ\_WEIGHT| GOODBYE | CHOOSE\_MODE|            | RUN
RESET       |  clear tare|  Show Reset |CLEAR\_TARE | GOODBYE | CHOOSE_MODE |            | RUN
OFF         |            |Show Shutdown|  x         |  x      | x           |            | x    

- 2 Extra credit: Al Sweigart wrote many small games in Python. They are keyboard input so
they don’t have very fancy graphics. As with toys, most games have a huge state
machine. Document the state machine for one of the games, suggested examples are
blackjack.py, conwaysgameoflife.py, snailrace.py, zombiebitefight.py,and montyhall.py.
You do not need it to run to play the game but if you do and don’t have python set up,
you can put them in a new Python notebook at https://colab.research.google.com/

<< [Exercise 4](./Exercise_4.md) -- [Assignments](./README.md) -- [Exercise 6](./Exercise_6.md) >>

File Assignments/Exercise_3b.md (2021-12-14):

# SPI Flash Test Code

Unfortunately, the SPI Flash we need to test the Key-Value storage system is on backorder. The
KVStore only uses the read, write, and erase functions from the SPI Flash subsystem. Create a
small simulator so you can test the KVStore. Write a test for your simulator that uses the read,
write and erase functions.
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

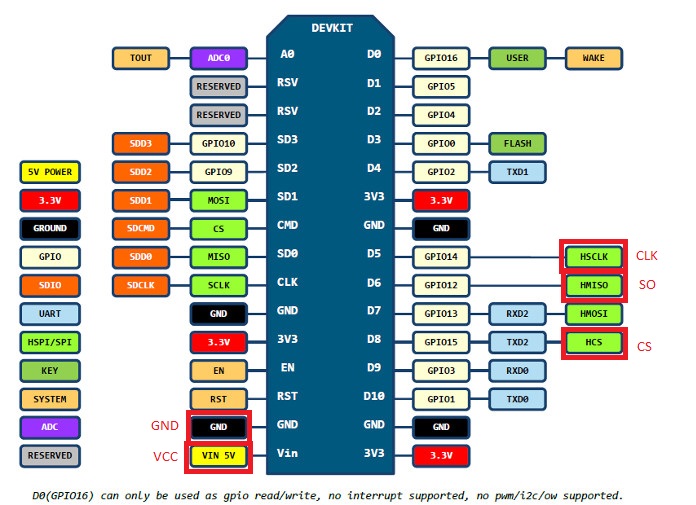
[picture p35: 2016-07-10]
pics/NodeMCU_v1.0_pinout.jpg

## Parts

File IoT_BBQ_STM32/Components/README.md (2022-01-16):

See https://github.com/STMicroelectronics/STM32CubeL4/tree/master/Drivers/BSP/Components

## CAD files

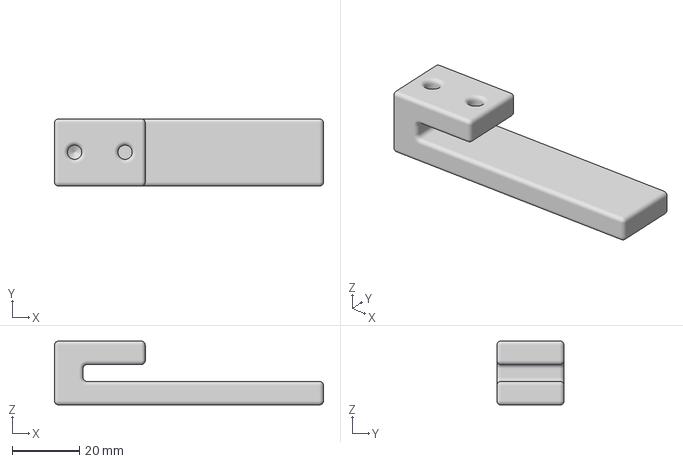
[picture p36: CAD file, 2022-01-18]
3DPrint/HX711 Test Jig/HX711 Test Jig v1 Fusion360.3mf
80.0 x 20.0 x 19.0 mm

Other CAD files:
3DPrint/HX711 Test Jig/HX711 Test Jig v1.step
3DPrint/HX711 Test Jig/HX711 Test Jig v1 PrusaSlicer.3mf
3DPrint/HX711 Test Jig/HX711 Test Jig v1.f3d

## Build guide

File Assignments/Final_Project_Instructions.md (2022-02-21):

# Final Project Instructions.

From [supplied document](https://drive.google.com/file/d/1yAi_6VQNstb2ZfA8rd6qKzKoh7N5YmEZ/view):

Your final project is to design and build a simple system that solves a problem you find
interesting. The final project is intended to bring together the course topics in a form that can be
shared with prospective employers.

The project was described in the Final Project video (see Week 1 Lecture - Final Project
Overview. The slides have the essential information.

Keeping up with the course exercises will help you finish the project without undue effort at the
end of the course. That said, students are expected to spend 10-15 hours on this project in
addition to the exercises. That is not a lot of time so you’ll have to be efficient and focused.

While the lectures have talked about grandiose ideas, please keep your system simple,
explainable, and reuse code.

## Minimum Project Requirements
The project must:

(a) Use a Cortex-M processor
(b) Have a button that causes an interrupt
(c) Use at least three peripherals such as ADC, DAC, PWM LED, Smart LED, LCD,
sensor, BLE
(d) Have serial port output
(e) Implement an algorithmic piece that makes the system interesting
(f) Implement a state machine

You are not required to use a HAL but it is encouraged. In fact, write as little code as possible,
reusing whatever you can, while keeping in mind licensing.

### Cortex-M Processor
Any Cortex-M processor can be used. The STM32 and the Discovery boards were
recommended but any Cortex-M is good. Students may use a processor/board simulator
instead of physical hardware (please notify a mentor if you intend to use a simulator).

### Button
The system should have a button that causes an interrupt. What the interrupt does is up to you.
The goal here is to show a simple GPIO interrupt handler being used.

### Peripherals
The system should interact with at least three peripherals. The peripherals suggested include
ADC, DAC, PWM LED, Smart LED, LCD, SPI sensor, and BLE. However, any peripherals are
acceptable as long as they are not controlled by a simple GPIO. The peripherals may be
internal to the microcontroller (like an on-board ADC) or external (SPI Flash, I2C sensor, PWM
speaker). There should be three different peripherals used.

### Serial Port
In addition to the peripherals, the system should have a serial port configured for debugging.
This may be simple logging or it may include a command line interface.

### Algorithm
The system should have an application, it should do something. Exactly what it does is up to
you, hopefully it is something that interests you.
Many examples were given in the final project lecture (slides). You may use one of those or
develop your own idea.

### State Machine
The system should include a basic state machine with at least three states. This may be part of
your algorithmic element. Also, using a command line on the serial port fulfills this requirement.

## Deliverables

The final project will be delivered as:

(a) Video of the system working as intended (link to mp4 or youtube)
(b) Write up of the system (PDF or Google docs report).
(c) Link to the code

These will be submitted to assignment-submissions in Discord or emailed to Jeff Hurd. 
Please submit links to all three deliverables as part of one message.
Bonus points are available by including one of these:

 * An analysis of the power used in the system (expected vs actual)
 * Implementation of firmware update with a description in the report of how it works
 * A description of profiling the system to make it run faster

Additional bonus points are available by having a version control history showing the
development process

### Video
A two to five minute video will be used to give an introduction and show the functionality of the
system. This does not need to have high production values, it is intended as a simple check of
the system. Talking about the system as you film is great.

### Report

The written part of the assignment is an introduction to the system for another programmer. The
write up should include:

 * Application description
 * Hardware description
 * Software description
	-  Describe the code in general
	-  Describe the parts you wrote in some detail (maybe 3-5 sentences per module)
	-  Describe code you re-used from other sources, including the licenses for those
 * Diagram(s) of the architecture
 * Build instructions
	-  How to build the system (including the toolchain(s))
		-  Hardware
		- Software
	-  How you debugged and tested the system
 * Future
	-  What would be needed to get this project ready for production?
	-  How would you extend this project to do something more? Are there other features you’d like? How would you go about adding them?

 * Grading
	-  Self assessment of the project: for each criteria, choose a score (1, 2, 3) and explain your reason for the score in 1-2 sentences.
	-  Have you gone beyond the base requirements? How so?

### Link to the Code
The code will be reviewed for clarity and that it meets the minimum project goals. Please make it
clear which files are written or significantly modified by you.

# Submission

See [Final Project Submission](./Final_Project_Submission.md)

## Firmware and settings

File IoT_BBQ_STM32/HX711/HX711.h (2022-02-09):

#pragma once
#include "Common/globals.h"

#include <sys/_stdint.h>
#include <stm32l4xx_hal.h>

/**
 *
 * HX711 library for Arduino
 * https://github.com/bogde/HX711
 *
 * MIT License
 * (c) 2018 Bogdan Necula
 *
 * adapted to stm32l4xx_hal 
 * by gojimmypi 2021
 *
**/
#ifndef HX711_h
#define HX711_h

#define byte uint8_t 
#define INPUT             0x00
#define OUTPUT            0x01
#define LSBFIRST 0
#define MSBFIRST 1
#define HIGH 0x1
#define LOW  0x0
#define DEFAULT_OFFSET 0xffffbfda
#define DEFAULT_SCALE 104
class HX711
{

private:
    uint16_t PD_SCK; // Power Down and Serial Clock Input Pin
    uint16_t DOUT; // Serial Data Output Pin
    byte GAIN; // amplification factor
    long OFFSET = DEFAULT_OFFSET; // used for tare weight
    float SCALE = DEFAULT_SCALE; // used to return weight in grams, kg, ounces, whatever

public:

    HX711();

    virtual ~HX711();

    // Initialize library with data output pin, clock input pin and gain factor.
    // Channel selection is made by passing the appropriate gain:
    // - With a gain factor of 64 or 128, channel A is selected
    // - With a gain factor of 32, channel B is selected
    // The library default is "128" (Channel A).
    void begin(uint16_t dout, uint16_t pd_sck, byte gain = 128);

    // Check if HX711 is ready
    // from the datasheet: When output data is not ready for retrieval, digital output pin DOUT is high. Serial clock
    // input PD_SCK should be low. When DOUT goes to low, it indicates data is ready for retrieval.
    bool is_ready();

    // Wait for the HX711 to become ready
    void wait_ready(unsigned long delay_ms = 0);
    bool wait_ready_retry(int retries = 3, unsigned long delay_ms = 0);
    bool wait_ready_timeout(unsigned long timeout = 1000, unsigned long delay_ms = 0);

    // set the gain factor; takes effect only after a call to read()
    // channel A can be set for a 128 or 64 gain; channel B has a fixed 32 gain
    // depending on the parameter, the channel is also set to either A or B
    void set_gain(byte gain = 64);

    // waits for the chip to be ready and returns a reading
    long read();

    // returns an average reading; times = how many times to read
    long read_average(byte times = 10);

    // returns (read_average() - OFFSET), that is the current value without the tare weight; times = how many readings to do
    double get_value(byte times = 1);

    // returns get_value() divided by SCALE, that is the raw value divided by a value obtained via calibration
    // times = how many readings to do
    float get_units(byte times = 1);

    // set the OFFSET value for tare weight; times = how many times to read the tare value
    void tare(byte times = 10);

    // set the SCALE value; this value is used to convert the raw data to "human readable" data (measure units)
    void set_scale(float scale = 1.f);

    // get the current SCALE
    float get_scale();

    // set OFFSET, the value that's subtracted from the actual reading (tare weight)
    void set_offset(long offset = 0);

    // get the current OFFSET
    long get_offset();

    // puts the chip into power down mode
    void power_down();

    // wakes up the chip after power down mode
    void power_up();
};


#endif /* HX711_h */

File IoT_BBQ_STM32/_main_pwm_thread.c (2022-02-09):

/* Includes ------------------------------------------------------------------*/
#include "Common/globals.h"
#include <stm32l4xx_hal.h>

#include "_Init/startup.h"
#include "_Init/Init_GPIO.h"
#include "Tasks/task_weight_monitor.h"
#include "Flash/Flash_Sim_Demo.h"
#include "Flash/spi_flash.h"

#include "LED/LED.h"
#include "UART/UART.h"
#include "DISPLAY/DISPLAY.h"
#include "UART/int_to_string.h"
#include "Tasks/state_machine.h"
#include "LPS22HB/stm32l475e_iot01_psensor.h"
#include "HTS221/stm32l475e_iot01_hsensor.h"
#include "HTS221/stm32l475e_iot01_tsensor.h"

#define configADJUSTED_HEAP_SIZE	( configTOTAL_HEAP_SIZE - portBYTE_ALIGNMENT )

static uint8_t buffer[] = "Global Variable: Hello World";

static int myNotInitializedVariable;
static int myInitializedVariable = 42;

// How many bits are one in a given 32-bit uint?

static size_t BitCount(uint32_t n)
{
    size_t res = 0;
    uint32_t pos = 1; // ensure this is the same bit size as parameter!
    for (size_t i = 0; i < 32; i++)
    {
        // if the and operation is non-zero, we found a 1 bit
        if (n & pos)
        {
            res++;  
        }
        
        // get ready to look at the next bit position
        pos = (pos << 1);

        // no sensee in continuing if we found the answer
        if (pos > n)
        {
            break;
        }
    }
    return res;
}

static size_t BitCountLeadingZeros(uint32_t n)
{
    const int BitsToCount = 32;
    size_t res = 0;
    uint32_t pos = 1; // ensure this is the same bit size as parameter!
    
    for (size_t i = 0; i < BitsToCount; i++)
    {
        // get ready to look at the next bit position
        pos = (pos << 1);

        // no sensee in continuing if we found the answer (in this case the mask is larger than our inspection number
        if (pos > n)
        {
            res = (i + 1); // zero based, so we need to add one
            break;
        }
    }
    
    // if we actually found leading zeros, the quantity is the total number of bits minus the position where we stopped looking
    if (res)
    {
        res = BitsToCount - res;  
    }
    
    return res;
}

/*
    On [-1000..+1000] range with 0.001 step average error is: +/- 0.000011, max error: +/- 0.000060
    On [-100..+100] range with 0.001 step average error is:   +/- 0.000009, max error: +/- 0.000034
    On [-10..+10] range with 0.001 step average error is:     +/- 0.000009, max error: +/- 0.000030
    Error distribution ensures there's no discontinuity.
*/

const double PI          = 3.141592653589793;
const double HALF_PI     = 1.570796326794897;
const double DOUBLE_PI   = 6.283185307179586;
const double SIN_CURVE_A = 0.0415896;
const double SIN_CURVE_B = 0.00129810625032;

double cos1(double x) {
    if (x < 0) {
        int q = -x / DOUBLE_PI;
        q += 1;
        double y = q * DOUBLE_PI;
        x = -(x - y);
    }
    if (x >= DOUBLE_PI) {
        int q = x / DOUBLE_PI;
        double y = q * DOUBLE_PI;
        x = x - y;
    }
    int s = 1;
    if (x >= PI) {
        s = -1;
        x -= PI;
    }
    if (x > HALF_PI) {
        x = PI - x;
        s = -s;
    }
    double z = x * x;
    double r = z * (z * (SIN_CURVE_A - SIN_CURVE_B * z) - 0.5) + 1.0;
    if (r > 1.0) r = r - 2.0;
    if (s > 0) return r;
    else return -r;
}

double sin1(double x) {
    return cos1(x - HALF_PI);
}



void PWM_Thread1(void const *argument)
{
    int n;
    n = BitCount(0xF); // 4
    n = BitCount(0x0); // 0
    n = BitCount(0x1); // 1
    n = BitCount(21); // 3
    n = BitCount(0xFFFF); // 16
    n = BitCount(0xFF000000); // 8
    n = BitCount(0xFFFFFFFF); // 32

    n = BitCountLeadingZeros(0xF); // 28
    n = BitCountLeadingZeros(0x0); // an interesting case that "0" is not counted in the other 31 digits of leading zeros
    n = BitCountLeadingZeros(0x1); // also 31
    n = BitCountLeadingZeros(21); // 27 leading zeros for 10101
    n = BitCountLeadingZeros(0xFFFF); // 16
    n = BitCountLeadingZeros(0xFF000000); // 0
    n = BitCountLeadingZeros(0xFFFFFFFF); // 0
    
    // long thisStackSize = __process_stack_size__; // this does not work (why??)
        
    // see https://stackoverflow.com/questions/20059673/print-out-value-of-stack-pointer
    // locally allocated variables are on the stack, so get the address:
    void* p = NULL;
    volatile long myStackPointer = (long)((void*)&p);
    
    void* q = NULL;
    volatile long myStackPointer2 = (long)((void*)&q);

    int* r = (int*)0xBEAD;
    volatile long myStackPointer3 = (long)((void*)&r);
        
    static uint8_t CrLf[] = "\n\r";
       
    static uint8_t StackMessage[]        = "Stack     = ";
    static uint8_t StackMessageHex[]     = "Stack     = 0x";
    static uint8_t HeapMessageHex[]      = "Heap      = 0x";

    static uint8_t HeapMessageSizeHex[]  = "Heap Size = 0x";
    static uint8_t HeapMessageFreeHex[]  = "Heap Free = 0x";
 
    static uint8_t InitMessageHex[]      = "Initialized     = 0x";
    static uint8_t NotInitMessageHex[]   = "Not Initialized = 0x";

    long myHeapSize = configADJUSTED_HEAP_SIZE;
        
    size_t myHeapFreeSize = xPortGetFreeHeapSize();
   
    volatile long myHeapPointer = (long)pvPortMalloc(0); // this returns a NULL pointer
    myHeapPointer = (long)pvPortMalloc(1); // a non-zero param returns heap pointer

    // UART_init();
    
    // Print global variable buffer
    UART_TxMessage(buffer, sizeof(buffer));
    UART_TxMessage(CrLf, sizeof(CrLf));

    // show decimal value of Stack pointer
    UART_TxMessageIntValue(StackMessage, sizeof(StackMessage), myStackPointer);
    UART_TxMessage(CrLf, sizeof(CrLf));

    // show hex value of current stack pointer
    UART_TxMessageIntValueHex(StackMessageHex, sizeof(StackMessageHex), myStackPointer);
    UART_TxMessage(CrLf, sizeof(CrLf));

    // show hex value of current heap pointer (xstart is static, not available)
    UART_TxMessageIntValueHex(HeapMessageHex, sizeof(HeapMessageHex), myHeapPointer);
    UART_TxMessage(CrLf, sizeof(CrLf));

    // show hex value of current heap size
    UART_TxMessageIntValueHex(HeapMessageSizeHex, sizeof(HeapMessageSizeHex), myHeapSize);
    UART_TxMessage(CrLf, sizeof(CrLf));

    // show free heap free size
    UART_TxMessageIntValueHex(HeapMessageFreeHex, sizeof(HeapMessageFreeHex), myHeapFreeSize);
    UART_TxMessage(CrLf, sizeof(CrLf));

    
    UART_TxMessage(CrLf, sizeof(CrLf));
    UART_TxMessage(CrLf, sizeof(CrLf));
    UART_TxMessage(CrLf, sizeof(CrLf));
    UART_TxMessage(CrLf, sizeof(CrLf));

    // show Initialized Variable Address
    UART_TxMessageIntValueHex(InitMessageHex, sizeof(InitMessageHex), (long)&myInitializedVariable);
    UART_TxMessage(CrLf, sizeof(CrLf));

    // show Uninitialized Variable Address
    UART_TxMessageIntValueHex(NotInitMessageHex, sizeof(NotInitMessageHex), (long)&myNotInitializedVariable);
    UART_TxMessage(CrLf, sizeof(CrLf));

    volatile int checkValue = myInitializedVariable;
    
    
    //    static char numStr[32];
    //    int_to_string(numStr, 32, 42);
    //    UART_TxMessage(numStr, 32);
    
        // workspace/STM32CubeL4/Middlewares/Third_Party/FreeRTOS/Source/portable/MemMang/heap_1.c
    pvPortMalloc(0);
    myHeapFreeSize = xPortGetFreeHeapSize();
    pvPortMalloc(0x10);
    myHeapFreeSize = xPortGetFreeHeapSize();
    pvPortMalloc(0x21);
    myHeapFreeSize = xPortGetFreeHeapSize();
    pvPortMalloc(0);

    
    (void) argument;
    int32_t CH1_DC = 0;
 
  
    static uint8_t PressureMessage[] = "Pressure = ";
    static uint8_t HumidityMessage[] = "Humidity = ";
    static uint8_t TemperatureMessage[] = "Temperature = ";    
    static uint8_t ThisTimerMessage[] = "Timer = 0x";
    float thisValue;
    
    for (;;)
    {

        while (1)
        {
            //            int timerValue = __HAL_TIM_GET_COUNTER(&htim2);
            //
            //            // UART_TxMessageIntValueHex(ThisTimerMessage, bufferLenth, (long)htim2.Instance->CNT);
            //            UART_TxMessageIntValueHex(ThisTimerMessage, bufferLenth, (long)timerValue);
            //            UART_TxMessage(CrLf, bufferLenth);
            
            //            osDelay(2000);  // This causes a hard fault!
            static const TickType_t xDelay = 2000 / portTICK_PERIOD_MS;
            osDelay(xDelay); // this does NOT cause a hard fault

            portENTER_CRITICAL();
            // TODO consider mutex instead
            thisValue = BSP_PSENSOR_ReadPressure();
            portEXIT_CRITICAL();
            
            UART_TxMessageIntValue(PressureMessage, sizeof(PressureMessage), (long)thisValue);
            UART_TxMessage(CrLf, sizeof(CrLf));
            osDelay(2000);
            
            //            thisValue = BSP_HSENSOR_ReadHumidity();
            //            UART_TxMessageIntValue(HumidityMessage, bufferLenth, (long)thisValue);
            //            UART_TxMessage(CrLf, bufferLenth);
            //            
            //            portENTER_CRITICAL();
            //            thisValue = BSP_TSENSOR_ReadTemp();
            //            portEXIT_CRITICAL();   
            //            
            //            UART_TxMessageIntValue(TemperatureMessage, bufferLenth, (long)thisValue);
            //            UART_TxMessage(CrLf, bufferLenth);
            //            
            //            osDelay(2000);
            
            //            while (CH1_DC < 65535)
            //            {
            //                TIM2->CCR1 = CH1_DC;
            //                CH1_DC += 70;
            //                osDelay(10);
            //            }
            //            while (CH1_DC > 0)
            //            {
            //                TIM2->CCR1 = CH1_DC;
            //                CH1_DC -= 70;
            //                osDelay(10);
            //            }
        }
        
    }
}

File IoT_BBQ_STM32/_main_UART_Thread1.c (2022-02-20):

#include "Common/globals.h"
#include <stm32l4xx_hal.h>
#include "UART/UART.h"
#include "_main_UART_Thread1.h"

void UART_Thread1(void const* argument) {
    (void)argument;
    const TickType_t xDelay = 1350 / portTICK_PERIOD_MS;
    static uint8_t buffer[1];
    static uint8_t UART_Message[] = "Hello UART!\n\r";
        
    for (;;)
    {
        UART_TxMessage(UART_Message, sizeof(UART_Message));
            
        // don't starve RTOS. yield with delay:
        osDelay(xDelay);
    }
}

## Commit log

2016-07-11 web page sample pic
2016-07-12 add init.lua. no diagnostic printing
2021-11-25 initial arduino library copy from bogde/HX711
2021-11-25 ported the easy stuff off Arduino to stm32l4xx_hal
2021-11-25 original arduino code
2021-11-25 adapted to stm32l4xx_hal
2021-11-25 initial port to stm32l4xx_hal
2021-11-25 add wiring_shift, HX711, DWT_STM32_DELAY
2021-11-26 working; fixed params to be uint16_t bit positions
    [HX711.cpp, HX711.h]
2021-11-26 project update with new wiring_shift, startup, main files
2021-11-29 add board info
2021-12-06 change target from stm32f2xx to our stm32l4xx
2021-12-06 initial SPI Flash simulation for read/wrire/erase
2021-12-06 testing with simulated SPI flash
2021-12-14 initial button-pushing example & docs
2021-12-14 add code links for Button press
2021-12-15 initial interrupts with LED_Mode
2021-12-15 resume LEDThread2 in AlwaysOff, proper blink
2022-01-09 initial SSD1306 from afiskon/stm32-ssd1306
2022-01-09 config for STM32L4
2022-01-13 initial working RTOS UART
2022-01-13 optional firebox temperature
2022-01-13 optional HAL for other STM32 CPUs
2022-01-13 I2C1 GPIO pin assignment conflicting info
2022-01-14 STM32CubeIDE closeup for I2C1 pins
2022-01-14 include link to VisualGDB I2C example
2022-01-17 initial display thread
2022-01-17 remove STM32F1xxxx references
2022-01-18 Initial Test Jig
    [HX711 Test Jig v1 Fusion360.3mf, HX711 Test Jig v1 PrusaSlicer.3mf, HX711 Test Jig v1.f3d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]
2022-01-22 LED init + getter/setter
2022-01-23 move LED2 code to LED lib
2022-01-23 add power LED doc
2022-01-23 add user LED doc
2022-01-23 add timers doc
2022-01-23 add timers / LED docs
2022-01-24 UART_TxMessage helpers
2022-01-24 PWM thread testing with assignment 8 code
2022-01-29 initial PWM and TIM2_IRQHandler
2022-01-31 gain / calibration / scale adjust
2022-01-31 UART_TxMessage for scale value
2022-01-31 add state machine. disable PWM thread
2022-01-31 print weight in integer not hex value
2022-01-31 working UART display
2022-02-01 add hts221 humidity and temperature sensor lib
2022-02-01 sensors added, but cannot read without hard fault
2022-02-01 compile with pressure/humidity/temp sensors
2022-02-01 wrap sensor call in IRQ disable/enable (still causes fault)
2022-02-02 working sensor readings added to thread
2022-02-02 working sensors in PWN and LED1 threads
2022-02-02 working sensors, no hard fault
2022-02-02 add new sensor pin docs
2022-02-04 UART message cleanup; use sizeof()
2022-02-04 remove UART from critical wrapper (confirmed working)
2022-02-05 initial working weight display in a thread!
2022-02-06 peel interrupts and pwm_thread to separate files
2022-02-06 peel LED_Thread1 to separate file
2022-02-06 remove duplicate LED_Thread1() prototype
2022-02-06 peel LED_Thread2 to separate thread
2022-02-06 reminder comments for missing portENTER_CRITICAL
    [_main_interrupt.c]
2022-02-06 project includes separate main thread source
2022-02-06 local STM32L475VG_flash.lds linker script
2022-02-07 see https://github.com/STMicroelectronics/STM32CubeL4/issues/61
2022-02-07 add reference to STM32CubeL4 issue 61
2022-02-09 initial ButtonLongPressFound
2022-02-10 RTOS tuning, DeviceCacheConfig(WithSave)
2022-02-10 print centered, long press tare
2022-02-10 button long press moved out of interrupt
2022-02-10 move CheckForLongPress() to button.h
2022-02-10 include button lib
2022-02-11 ScaleInit() at thread start
2022-02-12 power mode details
2022-02-12 Power Analysis Setup
2022-02-12 power fluctuation during debug pause
2022-02-12 blue pill power
2022-02-12 power tree
2022-02-12 power analysis day
2022-02-19 add Flash save and LPS22HB sensor info
2022-02-19 button info
2022-02-19 UART / Serial Port example
2022-02-19 add note on power analysis
2022-02-19 sample grading table
2022-02-20 move UART_Thread1 to separate file
2022-02-21 docs - weight sensor / future network

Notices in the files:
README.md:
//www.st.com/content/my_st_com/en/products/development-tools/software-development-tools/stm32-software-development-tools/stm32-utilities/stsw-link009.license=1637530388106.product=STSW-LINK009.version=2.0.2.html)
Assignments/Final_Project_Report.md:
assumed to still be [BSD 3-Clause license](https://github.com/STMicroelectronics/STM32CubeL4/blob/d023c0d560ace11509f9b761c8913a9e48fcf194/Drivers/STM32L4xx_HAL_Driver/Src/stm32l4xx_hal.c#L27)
